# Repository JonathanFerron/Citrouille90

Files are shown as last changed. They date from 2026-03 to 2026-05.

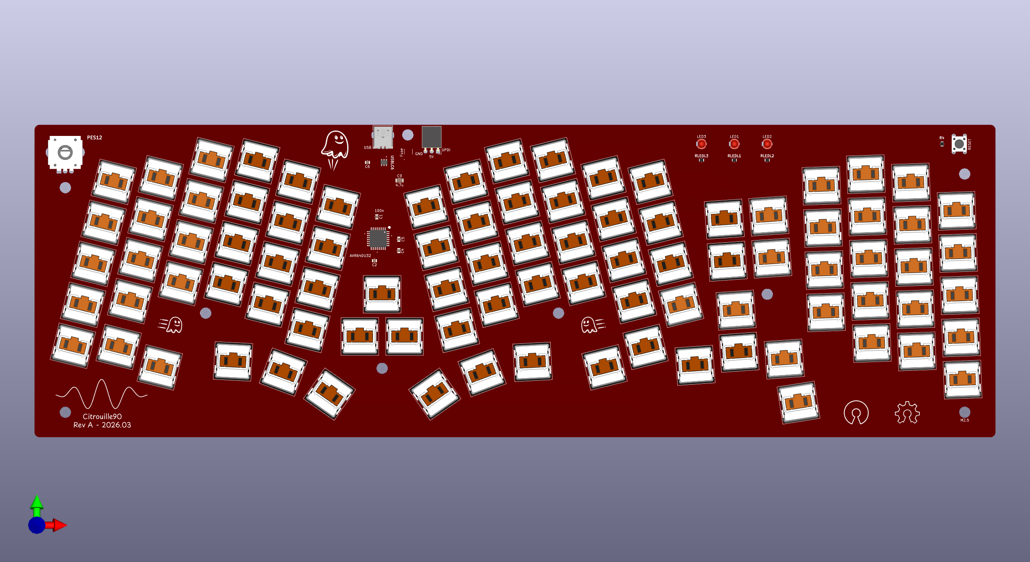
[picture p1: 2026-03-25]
doc/citrouille90 3D printout.png

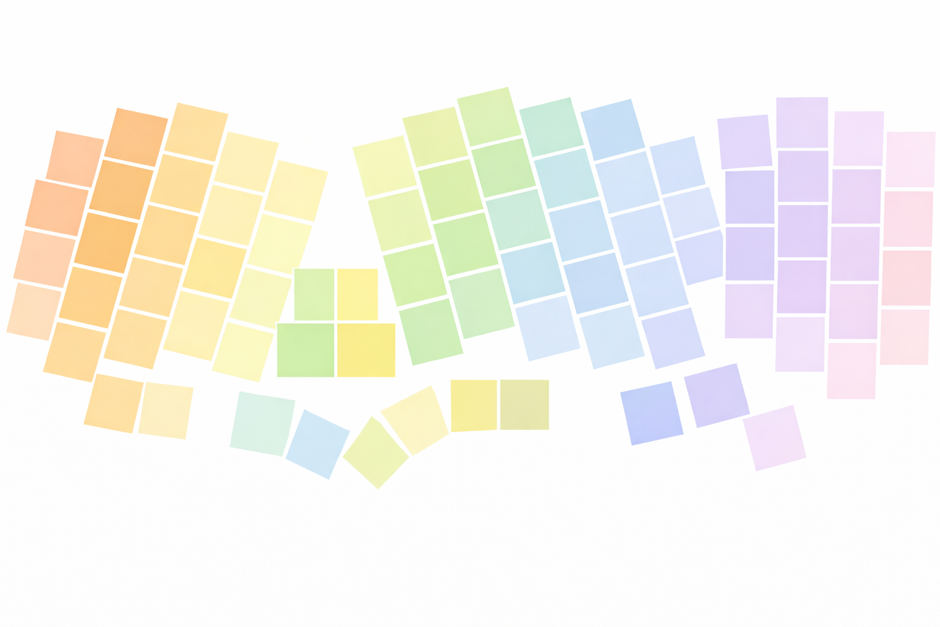
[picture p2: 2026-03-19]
doc/file_000000001a6c71f7b427a1b64068e487.png

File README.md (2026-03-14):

# Citrouille90
DIY keyboard project - AVR-DU based - Unibody, 90 keys plus encoder and leds - Covers PCB, FW (including BL) and case.

## Project Structure and Licensing

Copyright (C) 2026 Jonathan Ferron.

This project uses a multi-license stack to ensure the hardware and software remain open and reciprocal, while protecting the specific artistic assets of the design.

### 1. Hardware (PCB and Case)
The physical design files, including schematics, PCB layouts (KiCad/Gerber), and case files (STL/STEP/DXF), are licensed under the **[CERN Open Hardware Licence Version 2 – Strongly Reciprocal (CERN-OHL-S v2)](https://spdx.org/licenses/CERN-OHL-S-2.0.html)**.

*   **What this means:** You are free to make, modify, and distribute this hardware. However, if you distribute a modified version of these files or products based on them, you **must** provide the source files for your modifications under the same CERN-OHL-S v2 license.

### 2. Firmware
The source code for the keyboard firmware is licensed under the **[GNU General Public License version 3 (GPL v3)](https://www.gnu.org/licenses/gpl-3.0.txt)**.

*   **What this means:** You may run, share, and modify the software. If you distribute modified versions of the firmware, you **must** make the source code available to the recipients under the GPL v3.

### 3. Artwork
All artistic assets, including logos, icons, engravings, and custom keycap legends, are licensed under the **[Creative Commons Attribution-ShareAlike 4.0 International License (CC BY-SA 4.0)](https://creativecommons.org/licenses/by-sa/4.0/)**.

*   **What this means:** You may share and adapt the artwork, provided you give appropriate credit and distribute your contributions under the same license.

---

## Disclaimer
This project is provided "as is", without warranty of any kind, express or implied. Use of these designs and code is at your own risk.

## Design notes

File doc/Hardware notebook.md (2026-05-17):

# Citrouille90 — Hardware Notebook

**Project:** Citrouille90 (AVRDU.Enc.Choc)  
**Status as of writing:** KiCad project complete and ready to send to fab. Digikey and Mouser orders staged and ready to place.  
**Document purpose:** Personal pre-build reference and permanent record. Captures all hardware decisions with rationale, the complete BOM, and assembly notes.

---

## 1. Overview

| Parameter | Value |
|---|---|
| Name | Citrouille90 (AVRDU.Enc.Choc) |
| Keys | 90 (10 rows × 9 columns matrix) |
| Physical layout | 5 rows × 20 columns |
| Switch type | Kailh Choc V1 low-profile |
| Encoder | Bourns PES12, no integrated push switch |
| Reset | Dedicated 6mm tact switch (separate from encoder)  |
| USB | Full-Speed, USB Mini-B through-hole connector |
| MCU | AVR64DU32, TQFP-32 |
| PCB | 2-layer, 387 × 126 mm |
| Case | 3D-printed sandwich mount |
| Branding | "Citrouille90" in Playpen Sans + waveform + pumpkin logo |
| PCB board marker  | Rev A — 2026.03 |
| License (PCB/case)| CERN-OHL-S v2 (strongly reciprocal) |
| License (artwork) | CC BY-SA 4.0 |
| License (firmware)| GPL v3 |
| Copyright | © 2026 Jonathan Ferron |

---

## 2. MCU

**Part:** AVR64DU32-I/PT (TQFP-32, industrial temp range)

| Parameter | Value |
|---|---|
| Flash | 64 KB |
| SRAM | 8 KB |
| Clock | 24 MHz internal oscillator (no crystal needed) |
| GPIO (usable) | 23 |
| USB | Native Full-Speed, no external PHY |
| Programming interface | UPDI |
| VDD range | 1.8 V – 5.5 V |
| USB core supply | Internal 3.3 V regulator (VUSB) |
| Package | TQFP-32, 0.8 mm pitch |

No external crystal. No external USB PHY. VUSB (3.3 V for USB core) is generated entirely on-chip from VDD — no external 3.3 V regulator needed on the PCB. The 3.3 V domain is internal to the MCU and only powers the USB phy; all GPIO and logic runs at 5 V (VDD).

---

## 3. Power Architecture

**Configuration:** USB bus powered — Datasheet Power Configuration 5b.

```
USB Host (5 V VBUS)
    │
    ├─── Polyfuse (500 mA) ───┬─── 4.7 µF bulk cap (to GND)
    │                         │
    └─────────────────────────┴─── VDD (MCU pins 18, 28)
                                        │
                                   Internal regulator
                                        │
                                      VUSB (MCU pin 6) ── 100 nF (to GND)
```

### 3.1 Capacitor Budget

USB specification: total downstream capacitance ≤ 10 µF.

| Capacitor | Value  | Location |
|---|---|---|
| Bulk VBUS | 4.7 µF | Near USB connector, after polyfuse |
| VDD decoupling ×2  | 100 nF | At MCU VDD pins (18 and 28) |
| VUSB decoupling | 100 nF | At MCU VUSB pin (6), to GND only |
| ESD IC decoupling  | 100 nF | Near USBLC6-2 |
| Reset filter cap | 100 nF | At RESET pin (see section 8) |
| **Total** | **5.2 µF** | Well under 10 µF limit |

VUSB pin is decoupled to GND only — no external load on this pin. The internal regulator is sized for the USB PHY only.

### 3.2 Polyfuse

- **Part:** Bourns PTC reset fuse, 500 mA hold, 15 V, 1812 package
- Placed on VBUS line between USB connector and bulk capacitor
- Protects host port from overcurrent faults

---

## 4. GPIO Allocation

Total usable GPIO: **23 pins** (RESET and UPDI are dedicated, not counted).

| Function | Port / Pin  | Pin # (TQFP) | Notes |
|---|---|---|---|
| Matrix row 0 | PA0 | 30 | Pull-up input |
| Matrix row 1 | PA1 | 31 | Pull-up input |
| Matrix row 2 | PA2 | 32 | Pull-up input |
| Matrix row 3 | PA3 | 1 | Pull-up input |
| PWM LED A | PA4 | 2 | TCA0 WO4 output |
| PWM LED B | PA5 | 3 | TCA0 WO5 output |
| Matrix row 4 | PA6 | 4 | Pull-up input |
| Encoder A | PA7 | 5 | Plain input, no internal pull-up |
| Encoder B | PC3 | 9 | Plain input, no internal pull-up |
| Matrix row 5 | PD0 | 10 | Pull-up input |
| Matrix row 6 | PD1 | 11 | Pull-up input |
| Matrix row 7 | PD2 | 12 | Pull-up input |
| Matrix row 8 | PD3 | 13 | Pull-up input |
| Matrix row 9 | PD4 | 14 | Pull-up input |
| Matrix col 0 | PD5 | 15 | Output, input buffer disabled |
| Matrix col 1 | PD6 | 16 | Output, input buffer disabled |
| Matrix col 2 | PD7 | 17 | Output, input buffer disabled |
| Matrix col 3 | PF0 | 20 | Output, input buffer disabled |
| Matrix col 4 | PF1 | 21 | Output, input buffer disabled |
| Matrix col 5 | PF2 | 22 | Output, input buffer disabled |
| Matrix col 6 | PF3 | 23 | Output, input buffer disabled |
| Matrix col 7 | PF4 | 24 | Output, input buffer disabled |
| Matrix col 8 | PF5 | 25 | Output, input buffer disabled |

**Dedicated pins (not GPIO):**
- Pin 26: RESET (tact switch)
- Pin 27: UPDI (programming header)
- Pin 6: VUSB (decoupling cap only)
- Pins 18, 28: VDD
- Pins 7, 19, 29: GND

**No PORTB on AVR64DU32** — PORTB does not exist on this device.

---

## 5. USB Interface

### 5.1 Connector

- **Type:** USB Mini-B, through-hole
- **Position:** Top edge of PCB, aligned with middle of function key row

### 5.2 ESD Protection

- **Part:** USBLC6-2SC6 (SOT-23-6)
- Placed between USB connector and MCU D+/D− lines
- 100 nF decoupling cap on the IC supply pin
- No level shifting needed — PCB VDD is 5 V, MCU USB lines are 3.3 V tolerant via internal regulator

### 5.3 USB Shield RC Termination

- 1 MΩ resistor + 4.7 nF capacitor (0805, bottom layer) from USB shield to GND
- Reduces EMI from shield floating

### 5.4 Differential Pair Routing

- D+ and D− routed as matched-length differential pair
- No impedance-controlled routing required at Full-Speed (12 Mbit/s)
- Keep away from switching signals (matrix column drives, PWM)
- DRC rules: custom `.kicad_dru` with differential pair clearance and length-matching constraints

---

## 6. Key Matrix

| Parameter | Value |
|---|---|
| Electrical layout | 10 rows × 9 columns |
| Physical layout | 5 rows × 20 columns |
| Switch type | Kailh Choc V1 low-profile |
| Diode per switch | Yes — 1N4148W, SOD-123 |
| Diode orientation | COL2ROW (cathode toward column) |
| Scan direction | Drive column low, read row (pull-up) |
| Scan rate | 1000 Hz |
| Rollover | 6KRO (6-key rollover + modifiers) |

### 6.1 Diode Notes

1N4148W in SOD-123 is hand-solderable with a fine tip (T18-C2 or T18-D12) and flux. SOD-123 preferred over SOD-323 for easier hand assembly. Leaded solder (63/37, 290–315 °C).

---

## 7. Rotary Encoder

### 7.1 Part

**Bourns PES12** — mechanical rotary encoder, no integrated push switch.

| Parameter | Value |
|---|---|
| Max contact bounce | 5 ms |
| Max rotation speed | 60 RPM |
| Detents per revolution | 24 |
| Pulses per revolution | 24 |
| Detent-to-detent at 60 RPM  | ~41.7 ms |
| Quadrature transitions / detent | 4 |

### 7.2 RC Filter Circuit

Bourns-recommended RC filter on both encoder terminals A and B. This is a hardware decision that eliminates most software debounce complexity.

**Per pin:**

```
VDD (5 V) ──── 10 kΩ (pull-up) ────┬──── MCU GPIO (plain input, no internal pull-up)
                                    │
                              10 kΩ (series)
                                    │
                                Terminal (A or B)
                                    │
                              10 nF (to GND)

Terminal C ──── GND
```

**RC time constant:** 10 kΩ × 10 nF = **100 µs**

This suppresses contact bounce spikes faster than ~300–500 µs rise/fall before they reach the MCU. 100 µs is well below the 1 ms scan interval, so legitimate quadrature transitions are unaffected.

**Critical:** Configure encoder GPIO pins as plain input with **no internal pull-up**. The external 10 kΩ pull-up to VDD defines the operating point. Enabling the internal pull-up shifts the RC time constant and may degrade filtering.

### 7.3 Encoder Position

Top-left of PCB.

---

## 8. Reset Circuit

- **Switch:** 6 mm × 6 mm through-hole tact switch, SPST normally open
- **Position:** Top-right corner of PCB, silkscreen label "RESET"
- **Connection:** Switch one terminal to RESET pin (MCU pin 26), other terminal to GND

**RC filter (per AVR-DU datasheet recommendation):**

```
RESET pin (MCU pin 26) ──── 330 Ω ──── tact switch ──── GND
                │
              100 nF
                │
               GND
```

The 330 Ω series resistor limits current during ESD events. The 100 nF cap filters glitches. This is the AVR-DU datasheet recommended reset circuit.

**Behavior:** Hardware reset, always functional regardless of firmware state. Does not enter bootloader (GPR cleared on power-on reset; RESET pin behavior to be confirmed by GPR retention test on Curiosity Nano — see firmware notebook section 18.2).

---

## 9. LEDs

### 9.1 Power LED

| Parameter | Value |
|---|---|
| Type | 3 mm through-hole amber, diffused  |
| Drive | Fixed resistor from VDD — no GPIO, no PWM |
| Resistor | 2.2 kΩ |
| Target current | ~1.4 mA |
| Brightness intent | Dim but visible in low light; dim in bright room |
| Resistor placement | Near LED, not near MCU (reduces EMI, simplifies rework) |

**Calculation:** (5 V − 2.1 V forward voltage) / 2200 Ω ≈ 1.3 mA. Conservative — this LED is purely a power-on indicator.

### 9.2 Indicator LEDs (×2)

| Parameter | Value |
|---|---|
| Type | 3 mm through-hole amber, diffused  |
| Drive | MCU GPIO with PWM (TCA0) |
| Resistor each  | 390 Ω |
| Target current | ~7.5 mA at 100% duty cycle |
| Brightness | Firmware-controlled; clearly visible in bright room at full brightness |
| Viewing angle  | 60–100° preferred (soft glow, not a sharp spot) |

**Calculation:** (5 V − 2.1 V) / 390 Ω ≈ 7.4 mA. Reasonable for indicator use; well within MCU GPIO drive capability.

### 9.3 PWM Implementation

**Timer:** TCA0 in split mode — drives both LEDs independently from a single timer.

**Frequency:** 1465 Hz

1465 Hz is above the ~50–100 Hz flicker fusion threshold — no visible flicker at any duty cycle. PWM runs entirely in hardware; CPU has no per-cycle obligation (no matrix scan interference).

**Pin routing via TCAROUTEA (PORTMUX):**

TCA0 WO outputs available per PORTMUX setting:

| TCAROUTEA[2:0] | Port  | WO0  | WO1  | WO2  | WO3  | WO4  | WO5  |
|---|---|---|---|---|---|---|---|
| 0x0 | PORTA | PA0  | PA1  | PA2  | PA3  | **PA4** | **PA5** |
| 0x3 | PORTD | PD0  | PD1  | PD2  | PD3  | PD4  | PD5  |
| 0x5 | PORTF | PF0  | PF1  | PF2  | PF3  | PF4  | PF5  |

LED A → **PA4 (TCA0 WO4)**, LED B → **PA5 (TCA0 WO5)** with TCAROUTEA = 0x0 (PORTA). This avoids conflicts with matrix rows (PA0–PA3, PA6) and encoder (PA7).

### 9.4 LED Positions

Three LEDs arranged horizontally near top edge, offset to the right. Power LED leftmost, two indicator LEDs to its right.

---

## 10. UPDI Programming Header

- **Connector:** 3-pin through-hole header (2.54 mm pitch)
- **Pinout:** GND — UPDI — VCC
- **Position:** PCB top edge (preferred for easy access)
- **Programmer:** CH340-based SerialUPDI dongle (Adafruit UPDI friend)
- **Software:** avrdude with serialupdi programmer

**Critical rule: Never disable UPDI in fuses.** UPDI is the only recovery path if firmware is corrupted or the bootloader fails. Disabling it bricks the board and the only recovery path is a 12V UPDI programmer.

---

## 11. PCB Notes

| Parameter | Value |
|---|---|
| Layers | 2 |
| Dimensions | 387 × 126 mm |
| Mounting holes | M2.5, 7-hole layout |
| Silkscreen | Minimalist; logo + "Rev A — 2026.03" board marker |
| DRC rules | Custom `.kicad_dru` with USB differential pair clearance and length-matching |
| USB connector | Top edge, center of function row |
| Encoder | Top-left |
| LEDs | Top edge, right of center |
| RESET switch | Top-right corner |
| UPDI header | Top edge |

### 11.1 Routing Notes

- USB D+/D− as matched-length differential pair; keep away from matrix column drive lines and PWM pins
- Polyfuse on VBUS between connector and bulk cap
- ESD protection IC (USBLC6-2) placed close to USB connector, before the MCU
- 4.7 µF bulk capacitor placed near USB connector, after polyfuse
- 100 nF decoupling caps placed at their respective MCU pins, not clustered
- Resistor for power LED placed near LED (not near MCU)
- Encoder RC filter components placed close to encoder terminals, not at MCU side

---

## 12. Case

| Parameter | Value |
|---|---|
| Type | Sandwich mount |
| Material | 3D-printed PLA or PETG |
| Switch plate thickness | 2.2 mm (Kailh Choc V1 spec) |
| Parts | Top plate, bottom case, encoder knob |
| CAD source | Fusion 360 (`.f3d`), STEP export (`.step`) |
| STL exports | `top_plate.stl`, `bottom_case.stl`, `encoder_knob.stl` |
| Mounting | M2.5 screws through 7-hole pattern matching PCB |
| Feet | Rubber adhesive feet on bottom case |

---

## 13. Bill of Materials

### 13.1 MCU

| Qty | Description | Value / Part # | Package |
|-----|---|---|---|
| 1 | AVR64DU32 | AVR64DU32-I/PT | TQFP-32 |

### 13.2 Switches and Diodes

| Qty | Description | Value / Part # | Package |
|-----|---|---|---|
| 90  | Kailh Choc V1 switches | CPG135001D02 (or equiv.) | Through-hole, MX-spacing |
| 90  | Switching diodes | 1N4148W | SOD-123 |

### 13.3 Encoder and Reset

| Qty | Description | Value / Part # | Package |
|-----|---|---|---|
| 1 | Rotary encoder | Bourns PES12 | Through-hole |
| 1 | Encoder knob | To suit PES12 shaft | — |
| 1 | Reset tact switch | 6 mm × 6 mm SPST NO | Through-hole |

### 13.4 USB

| Qty | Description | Value / Part # | Package |
|-----|---|---|---|
| 1 | USB Mini-B connector | — | Through-hole |
| 1 | Polyfuse | Bourns PTC, 500 mA, 15 V | 1812 |
| 1 | ESD protection IC | USBLC6-2SC6 | SOT-23-6  |

### 13.5 Capacitors

| Qty | Description | Value | Voltage | Package | Notes |
|-----|---|---|---|---|---|
| 1 | Bulk VBUS capacitor | 4.7 µF | 16 V | 1206 | X7R or X5R ceramic, near USB connector |
| 5 | Decoupling capacitors | 100 nF | — | 0805 | 2× VDD (MCU), 1× VUSB (MCU), 1× ESD IC, 1× RESET filter |

### 13.6 Capacitors (Encoder Filter and USB Shield)

| Qty | Description | Value | Package | Notes |
|-----|---|---|---|---|
| 2 | Encoder RC filter caps | 10 nF | 0805 | One per encoder pin (A, B), pin to GND  |
| 1 | USB shield RC cap | 4.7 nF  | 0805 | USB shield to GND, with 1 MΩ |

### 13.7 Resistors

| Qty | Description | Value | Package | Notes |
|-----|---|---|---|---|
| 1 | Power LED current limit | 2.2 kΩ  | 0805 | ~1.4 mA at 5 V |
| 2 | PWM LED current limit | 390 Ω | 0805 | ~7.4 mA at 5 V, one per indicator LED |
| 1 | RESET series resistor | 330 Ω | 0805 | ESD protection on RESET pin |
| 2 | Encoder pull-up (per pin) | 10 kΩ | 0805 | To VDD, part of RC filter |
| 4 | Encoder series (per pin) | 10 kΩ | 0805 | Between terminal and MCU GPIO (2 per encoder pin pair — but 1 pull-up + 1 series per pin = 2 pins × 2 = 4 total) |
| 1 | USB shield termination | 1 MΩ | 0805 | USB shield to GND (with 4.7 nF cap) |

> **Encoder RC resistor count clarification:** 2 pins (A and B) × 2 resistors each (1 pull-up to VDD + 1 series to MCU GPIO) = **4 resistors of 10 kΩ** total for the encoder filter.

### 13.8 LEDs

| Qty | Description | Value / Part # | Package |
|-----|---|---|---|
| 1 | Power LED | 3 mm amber diffused | Through-hole  |
| 2 | Indicator LEDs | 3 mm amber diffused | Through-hole  |

Diffused preferred over clear — softer glow, 60–100° viewing angle, less eye-fatiguing at close range.

### 13.9 Programming Header

| Qty | Description | Value / Part # | Package |
|-----|---|---|---|
| 1 | UPDI header | 3-pin 2.54 mm male header | Through-hole  |

### 13.10 Hardware

| Qty | Description | Notes |
|-----|---|---|
| 7 | M2.5 screws | Length to suit plate + PCB + case stack |
| 7 | M2.5 nuts or standoffs | Matching |
| 4+  | Rubber adhesive feet | Applied to bottom of case |
| 90  | Kailh Choc-compatible keycaps | MBK, CFX, or similar Choc-spacing profile |

---

## 14. Assembly Notes

### 14.1 Soldering Notes

- Leaded solder preferred: 63/37, 290–315 °C
- SMD diodes (SOD-123): T18-C2 or T18-D12 tip, flux generously
- TQFP-32 MCU: drag solder with flux, wick bridges immediately
- ESD IC (SOT-23-6): small pads, flux and fine tip
- Through-hole components (switches, encoder, LEDs, reset switch, UPDI header): standard iron, 350 °C

### 14.2 Assembly Order (recommended)

1. SMD passives first (resistors, capacitors) — before through-hole, easier to access pads
2. ESD IC (USBLC6-2) and polyfuse
3. MCU (TQFP-32) — inspect under magnification, check for bridges before powering
4. USB connector
5. Reset tact switch and UPDI header
6. LEDs (check orientation — anode/cathode markings)
7. Encoder
8. Diodes (90×) — check cathode band direction (COL2ROW: cathode toward column pin)
9. Kailh Choc switches last (after all SMD and smaller TH components)

### 14.3 First Power-On Checklist

Before loading any firmware:
- [ ] Verify 5 V at VDD test point (no short to GND)
- [ ] Verify power LED illuminates
- [ ] Connect UPDI programmer, confirm avrdude detects AVR64DU32
- [ ] Read device signature to confirm correct MCU
- [ ] Flash test firmware (blink LED, confirm PWM pins respond)
- [ ] Test matrix continuity (short each switch, check scan output)
- [ ] Test encoder (confirm A/B pulses reach MCU pins)
- [ ] Test reset button (confirm system resets cleanly)

### 14.4 UPDI Recovery

If firmware is corrupted and USB is non-functional, UPDI is the only recovery path. Always keep the SerialUPDI programmer accessible.

---

## 15. Open Hardware Items

| Item | Status | Notes |
|---|---|---|
| Encoder knob selection | 🔧 Pending | Choose to suit PES12 shaft spec |
| 3D case design | 🔧 Pending | Switch plate 2.2 mm; Fusion 360 source to be created |

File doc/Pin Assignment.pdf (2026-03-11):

# AVR64DU32 — 32-Pin Package

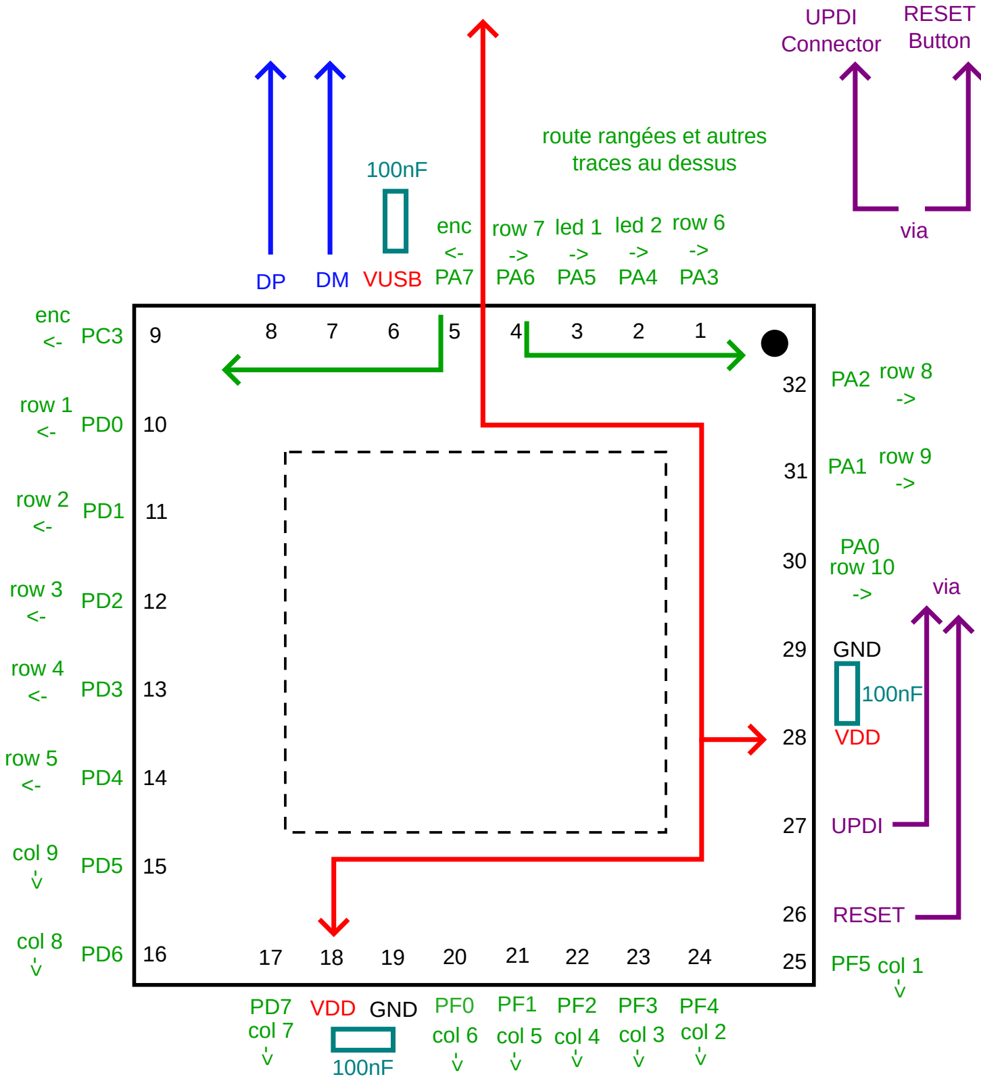
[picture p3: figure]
GND; VDD; UPDI; RESET; DM VUSB PA7; PD7 VDD GND PF0 PF1 PF2 PF3 PF4; row 7 ->; enc <-; led 1 ->; led 2 ->; row 6 ->; row 8 ->; row 9 ->; row 10 ->; row 1 <-; row 2 <-; row 3 <-; row 4 <-; row 5 <-; col 9; col 8 ->; col 7 ->; col 6 ->; col 5 ->; col 4 ->; col 3 ->; col 2 ->; col 1 ->; via; UPDI Connector; RESET Button; route rangées et autres traces au dessus

via pour chaque colonne
(route colonnes en dessous)

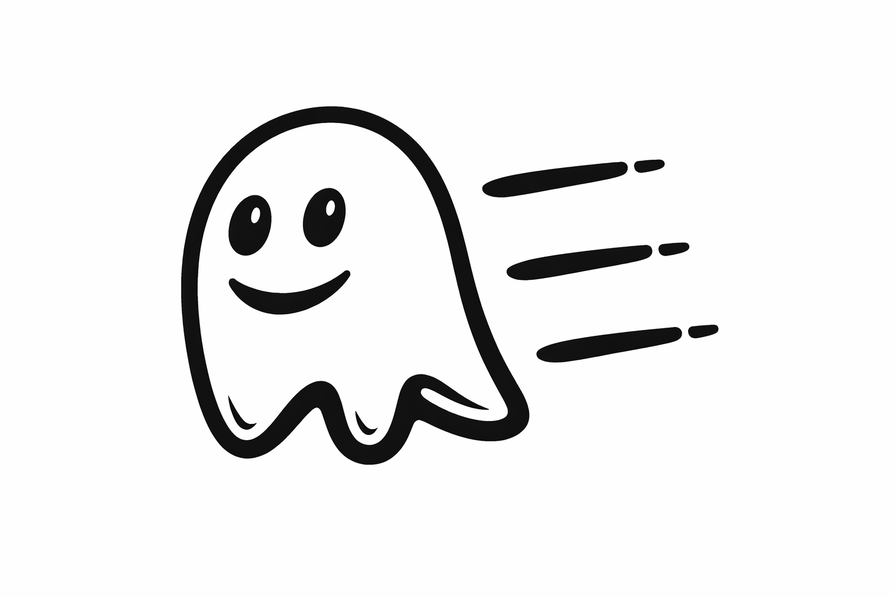
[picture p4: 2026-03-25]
doc/file_00000000e3d071fd9366121f5f05d2d4.png

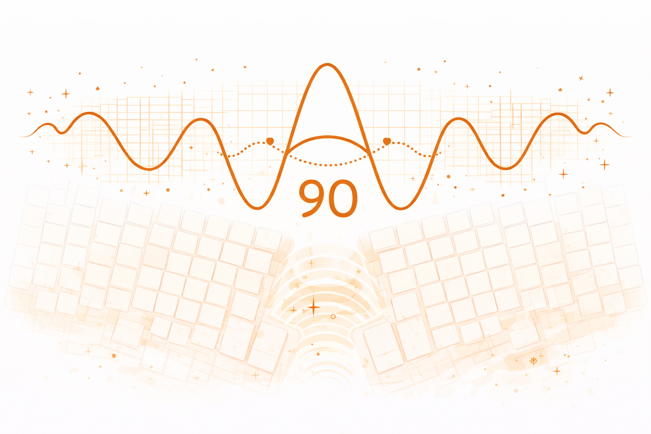
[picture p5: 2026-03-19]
doc/file_00000000508071f58be6d0860e3f69f2.png

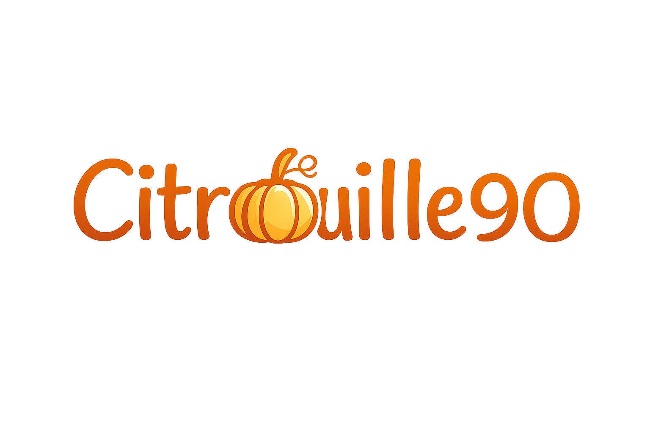
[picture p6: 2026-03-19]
doc/file_000000007074720cb7dd78ddb676f850.png

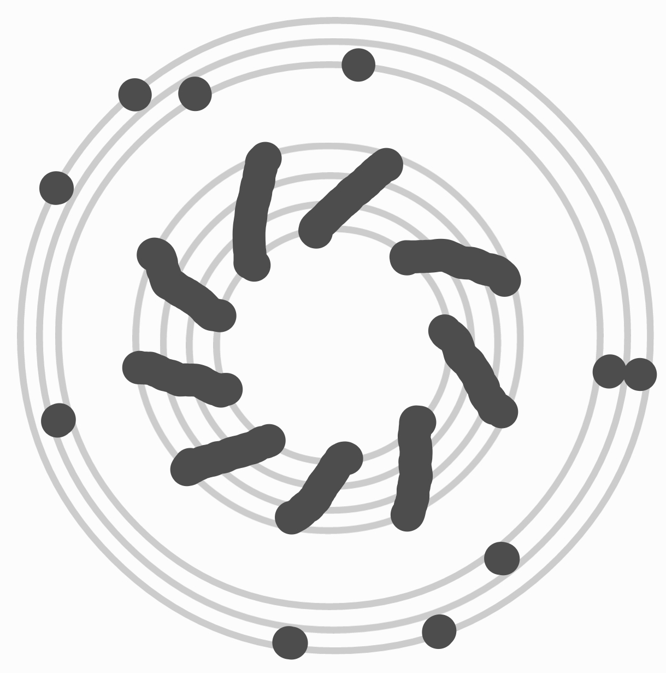
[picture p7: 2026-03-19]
doc/Screenshot_20260309_205730_Samsung Notes.jpg

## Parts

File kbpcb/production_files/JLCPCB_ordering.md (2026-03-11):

# JLCPCB ordering guidelines

The information below is aimed at helping users not familiar to PCB design and/or manufacturing to easily order Type S or Type H PCBs at JLCPCB.

JLCPCB already provides generic infornmation on how to order PCBs and assemble them, you'll find this information on the links below:
* https://jlcpcb.com/help/article/54-How-do-I-place-an-order
* https://jlcpcb.com/help/article/342-how-do-i-place-a-pcba-order

As for ordering FR4 plates, either full or half, the process is even simpler as there is no assembly process.  
In this case follow the same steps up to ***Advanced Options***.  
For the ***PCB Specifications*** section you can leave all options by default and just select the PCB color you want.

## Connecting to JLCPCB website

Go to https://jlcpcb.com website.



Click on *'Sign in'*, if you do not have an account it is time to create one by selecting *'New Customer? Start Here'*.

Once you are logged, you should see your user account displayed on the top right.

## Starting a new order

To start click on the *'Instant Quote'* button

You'll then have the following information displayed.



## Upload gerber file

Click on *'Add gerger file'* and select one of those files:
* **production_files/typeH/jlcpcb/GERBER-Phoenix_Project_No1-TypeH.zip** for the Type H PCB
* **production_files/typeS/jlcpcb/GERBER-Phoenix_Project_No1-TypeS.zip** for the Type S PCB

Wait a bit while the file is processed, to have the following information displayed:



PCB dimensions are automatically calculated and a price is already given with all defauts options.
In this section we will leave all the default parameters as is, with the exception of *'PCB Qty'* if you want to order more than 5 PCBs.

## Tweaking PCB Specifications

By default you will have the following parameters:



It is perfectly fine to keep them as is to have a working PCB, but will do a few tweaks.



I strongly recommend selecting *'LeadFree HASL'*:
* Go lead free, it is more environmentally friendly.
* It adds only 1.80$ to the cost of 5 PCB compared to default *'HASL(with lead)'*.
* *'ENIG'* adds 18.70$, a significant expense not justified in this case as no gold will be visible after soldering.

I selected *'Black'* for the PCB color(I love the satin finish of their black soldermask) but you can pick any color you want.  
If you select *'White'* the silkscreen color will then be black. 

## Tweaking High-spec Options

By default you will have the following parameters:



I removed the order number to have this:



Keep in mind that it adds 1.52$ to remove the order number.  
You can perfectly keep the option *'Remove Order Number'* to *'No'*, JLCPCB will automatically place this number on the PCB were it is the most appropriate, and will most probably place it on the cutout tabs that will later be snapped off(but no warranty on that).

## Advanced Options

No need to touch that.

## Tweaking PCB Assenbly

In this section:



Click the slide button on the right to open the following page:



We will change a few options here:



### PCBA Type

It must be set to *'Standard'* in order for:
* The WS2812 mini leds to be soldered.
* The Kailh hotswap sockets to be soldered.

### Assembly Side

We select *'Bottom Side'* as it is were all our components are placed.

### PCBA Qty

If you want to save some money you can select down to 2, but keep in mind that you will still have 5 PCBs manufactured if you ordered 5 for example, 3 of them will be shipped unpopulated.
The price difference may not be significent enough to have only 2 assembled PCBs though...

### Edge Rails/Fiducials

We select *'Added by customer'* as everything is prepared on the PCB design.

### Confirm Parts Placements

I'd suggest selecting *'Yes'*.  

I previously selected *'No'* as JLCPCB usually manage this part correctly and if they have any doubts they will contact you for confirmation.  
I have been contacted previously for the WS2812 mini leds and had to explain what to do for the placement and later confirm that their placement screenshot was correct.    

If you select *'Yes'* this will force you to manually confirm components placement before the PCBs are assembled.
They will probably come back to you anyway for the leds placement and maybe also for the Kailh hotswap sockets.
This is a bit cumbersome for non PCB designers but definitely doable and will allow you to check that no mistakes have been made.
I'll give more details on parts placement confirmation later on in this document. 

### Confirm parameters

Click on *'Confirm'* button when it is done, the following page appears:



### BOM and CPL files

Click on *'NEXT'*, the folowing page appears:



Click *'Add BOM File'* and select one of those files:
* **production_files/typeH/jlcpcb/BOM-Phoenix_Project_No1-TypeH.csv** for the Type H PCB
* **production_files/typeS/jlcpcb/BOM-Phoenix_Project_No1-TypeS.csv** for the Type S PCB

Click *'Add CPL File'* and select one of those files:
* **production_files/typeH/jlcpcb/CPL-Phoenix_Project_No1-TypeH.csv** for the Type H PCB
* **production_files/typeS/jlcpcb/CPL-Phoenix_Project_No1-TypeS.csv** for the Type S PCB

You should have the follwing page displayed:



Click on *'Process BOM & CPL'*

## Bill of Material page



This page shows something interesting as there is currently an inventory shortage for one component.
This can happen often as JLCPCB tend to wait that inventories are empty before ordering new components.  

You have two solutions.

1. Play the waiting game until all components are available to make an order.
2. Find a replacement for those components.

Solution 1 is the easiest and less risky one.

But solution 2 is not as compilcated as you may think, particularly for simple passive components like capacitors, resistors, diodes and fuses.  
In this case this the reference of a resettable fuse in an imperial 805 footprint, we could hope to easily find an equivalent in stock replacement.    
If you click on the search icon of this component, immediately on the left of the *'Qty'* column, the website will propose you several alternatives that should be compatible, like below.



The list shows possible choices, all 805 footprint, from the closest match possible to the least. The first choice is the reference we had already selected but out of stock, the next two ones are also out of stock, but the fourth one is in stock and a pretty good match so this is the one I selected for my order.



After clicking *'NEXT'* the website will compute a PCB assembly preview for you.  
Depending on the server load this can take some time, don't hesitate to refresh the page (F5) if it take too long.  
You should be greated with the following visual (I pressed the *'Bottom'* button at the top to show the bottom assembly).



Don't put much of an importance on the components placement and orientation, this display has not real value and it is advertised as is.  
Components can be wrongly oriented and even in the wrong position (can even be outside the PCB area) although I have to admit that JLCPCB have made significant progress since they proposed their PCBA service.  
People at JLCPCB will inspect the data and correct everything wrong and in case of doubt they will contact you for clarification (or if you asked for a placement review before going to assembly).  

You can click *'NEXT'* as soon as this page is displayed, this will go to the quote and order page.

## Quote & Order



You aleady have a price here, not including shipping costs and taxes, here it is 112$ for 5 fully assembled PCBs so around 23$ per PCB.  
For assembled PCBs you have to declare it's purpose in the *'Product Description'* drop down menu.  



I selected DIY for the description here.



Just click *'SAVE TO CART'* and you are mostly done, except for shipping selection and payment.



## About WS2812 mini polarity and placement

This is specific polarity information to correctly place WS2812 mini leds onto the PCB.
Those leds are designed in the BOM as D1 to D16.

Please be aware that the triangle cutout of the WS2812 mini led is not indicating pin 1, but pin 3 of the chip.
The WS2812 mini footprint indicates pin 1 on the silkscreen with a dot, diametrically opposite of pin 3 indicated by the triangle cutout.

See image below for a visual explanation:



In case you asked for manually inspecting the component placement before fabrication this is a good reference for you to inspect that this component is correcty placed.  
If JLCPCB ask you how to place this component you can just copy paste the previous text section with the image for explanation.

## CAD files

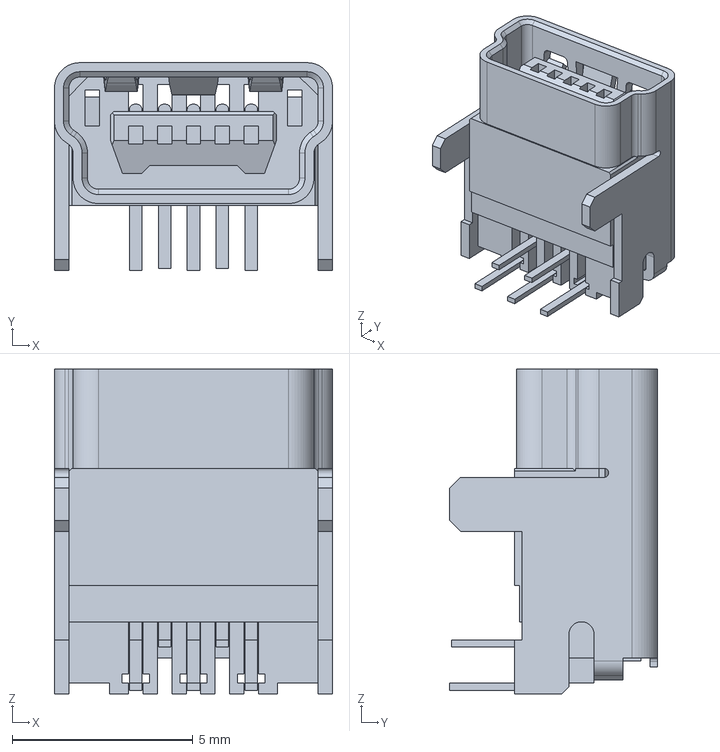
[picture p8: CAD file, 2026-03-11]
kbpcb/lib_3Dmodels/usb mini b connector.stp
7.70 x 5.75 x 9.00 mm

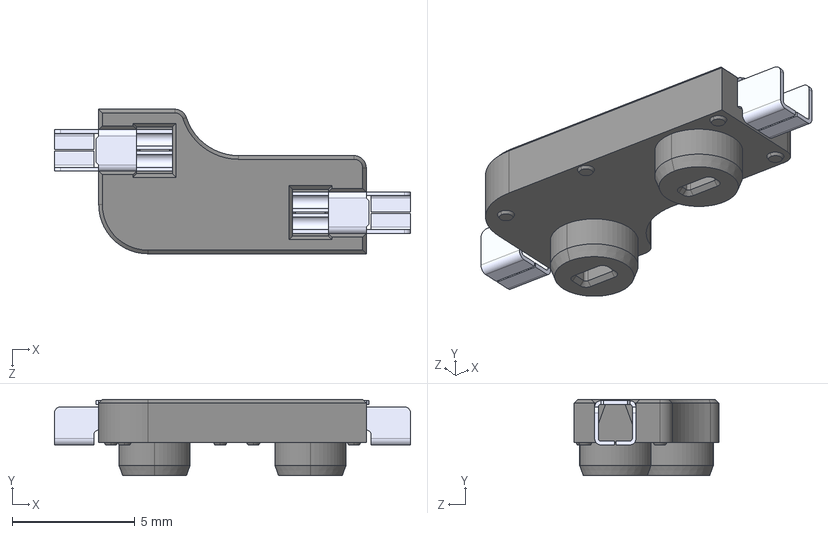
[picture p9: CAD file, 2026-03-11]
kbpcbold1/lib_3Dmodels/Kailh_PG151101S11.step
14.5 x 3.10 x 5.89 mm

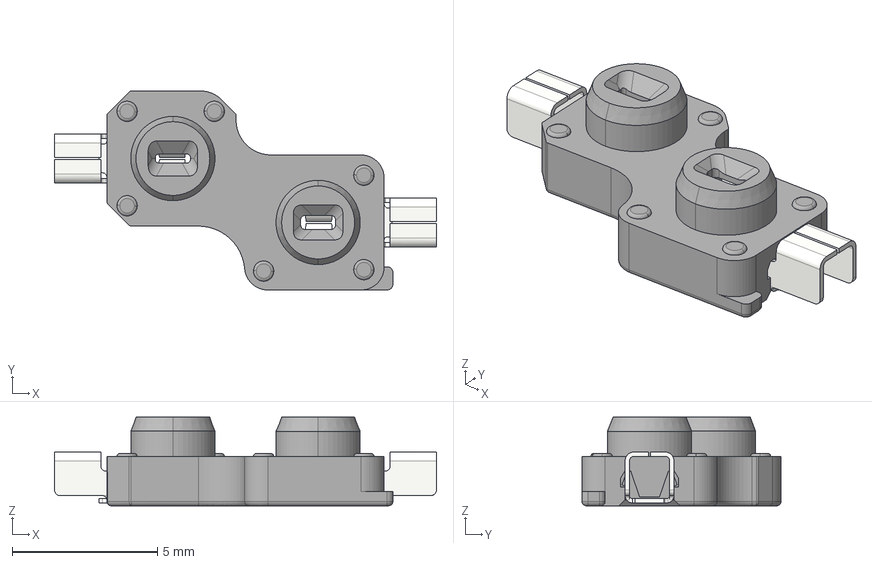
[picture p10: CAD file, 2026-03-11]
kbpcbold2/lib_3Dmodels/SW_Hotswap_Kailh_Choc_V1.stp
13.2 x 6.85 x 3.05 mm

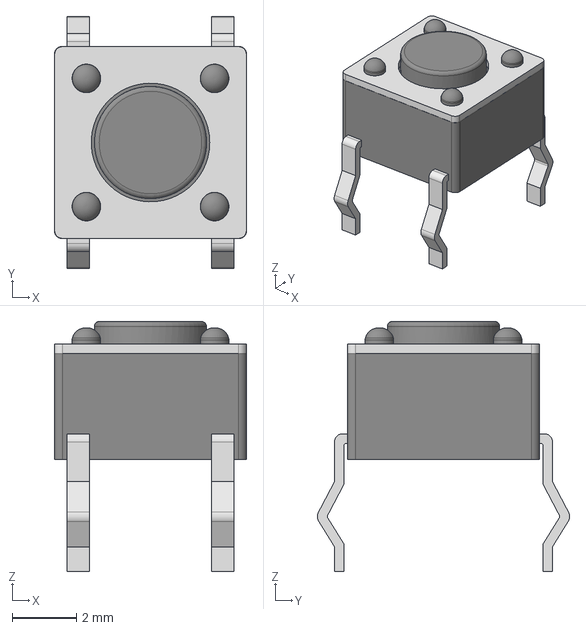
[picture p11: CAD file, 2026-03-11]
kbpcb/lib_3Dmodels/MJTP1230.stp
6.00 x 7.87 x 7.80 mm

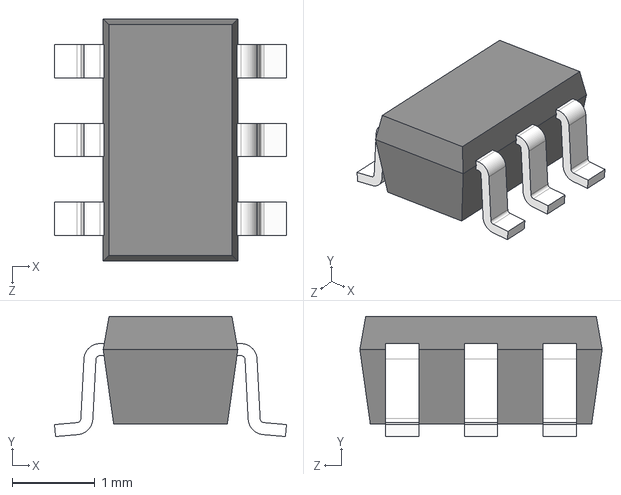
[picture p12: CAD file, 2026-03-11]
kbpcbold1/lib_3Dmodels/USBLC6-2SC6.step
2.80 x 1.45 x 2.92 mm

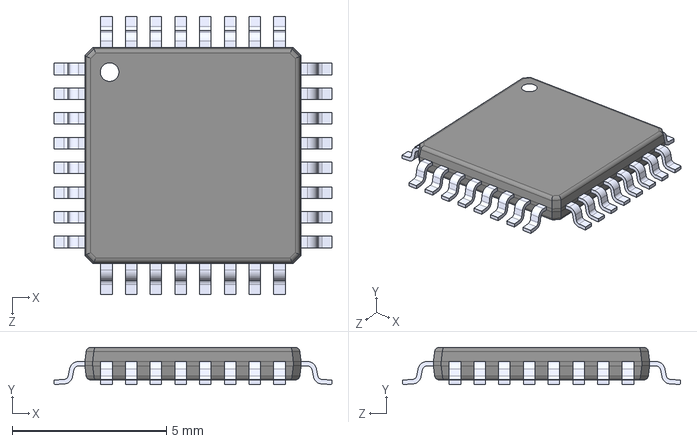
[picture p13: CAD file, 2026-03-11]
kbpcb/lib_3Dmodels/TQFP32 7x7.STEP
9.00 x 1.20 x 9.00 mm

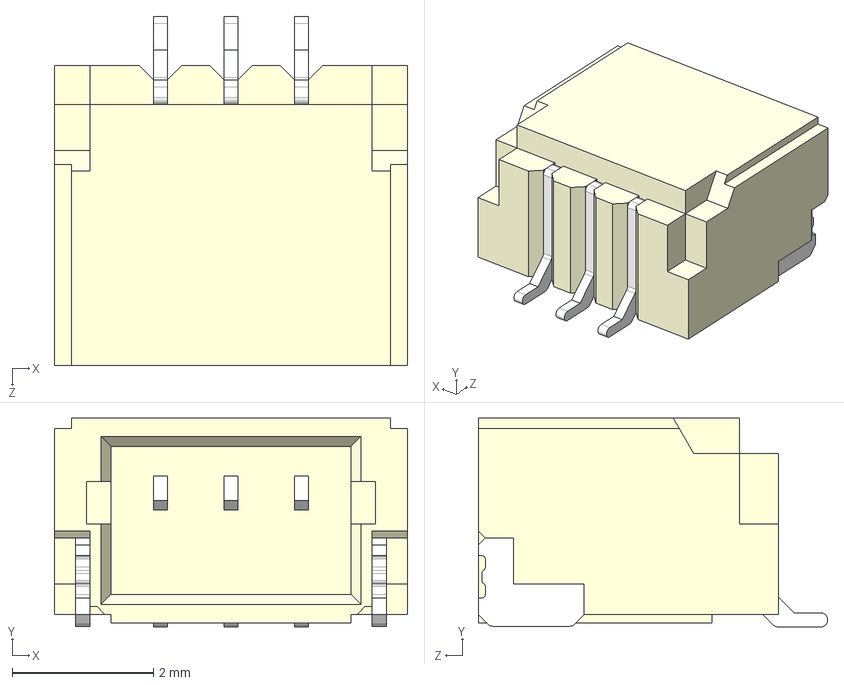
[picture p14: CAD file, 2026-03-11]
kbpcbold1/lib_3Dmodels/SM03B-SRSS-TB_LF__SN_.step
5.00 x 2.96 x 4.95 mm

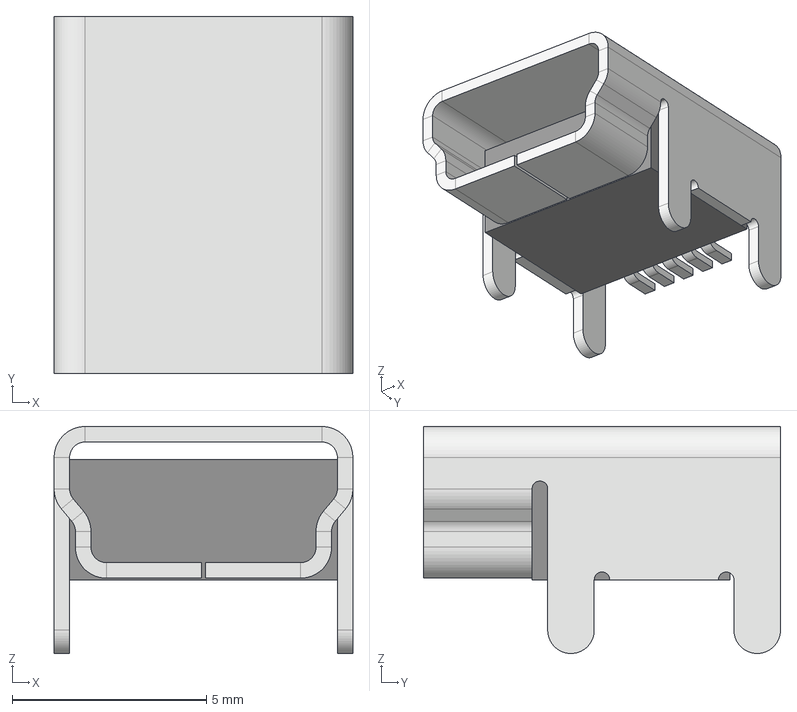
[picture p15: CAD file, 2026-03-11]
kbpcbold2/lib_3Dmodels/HRO-U-M-M5DD-W-1.step
7.70 x 9.20 x 5.85 mm
Pins
Plastic_Case

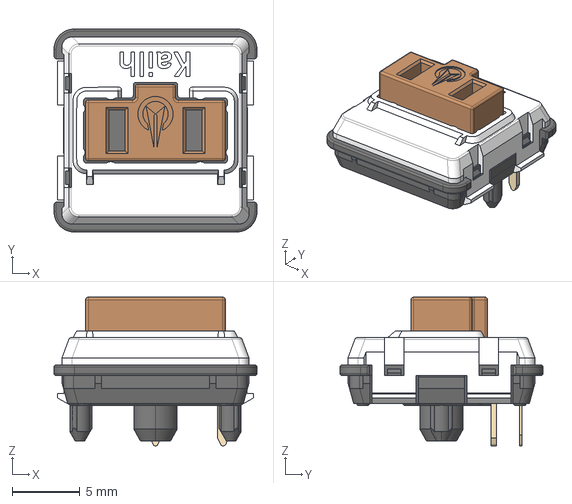
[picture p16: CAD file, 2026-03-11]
kbpcb/lib_3Dmodels/SW_Kailh_Choc_V1.stp
15.0 x 15.0 x 11.0 mm

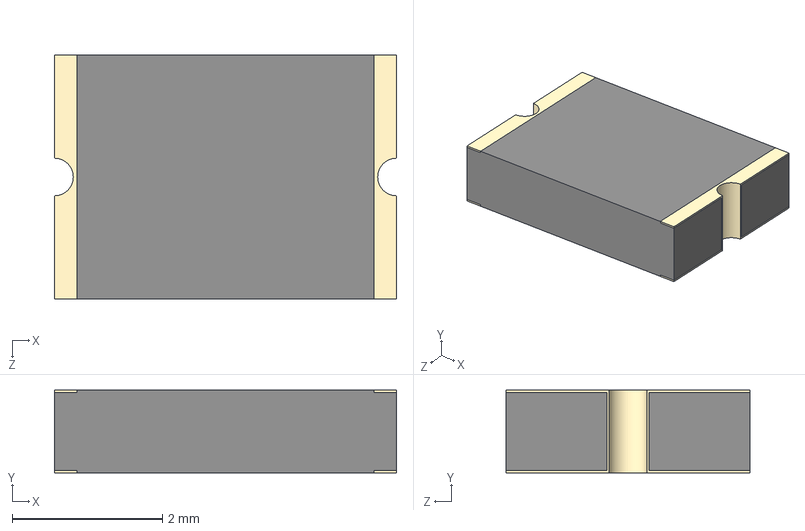
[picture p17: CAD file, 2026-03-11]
kbpcbold1/lib_3Dmodels/MF-MSMF050-2.STEP
4.55 x 1.10 x 3.24 mm

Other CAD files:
kbpcb/lib_3Dmodels/PES12-40S-N0024.stp
kbpcb/lib_3Dmodels/SM03B-SRSS-TB_LF__SN_.stp
kbpcbold1/lib_3Dmodels/PES12-40S-N0024.stp
kbpcbold1/lib_3Dmodels/SM03B-SRSS-TB_LF__SN_.stp
kbpcbold2/lib_3Dmodels/PES12-40S-N0024.stp
kbpcbold2/lib_3Dmodels/SM03B-SRSS-TB_LF__SN_.stp

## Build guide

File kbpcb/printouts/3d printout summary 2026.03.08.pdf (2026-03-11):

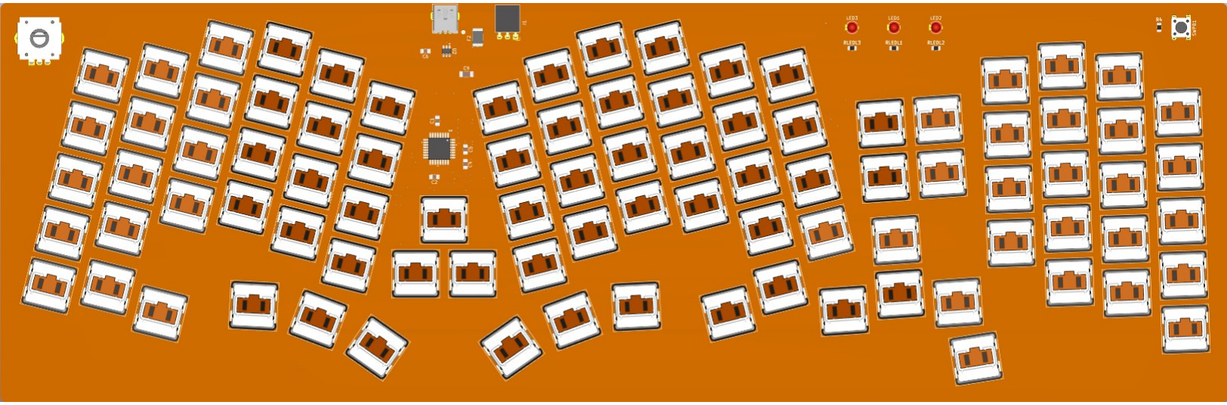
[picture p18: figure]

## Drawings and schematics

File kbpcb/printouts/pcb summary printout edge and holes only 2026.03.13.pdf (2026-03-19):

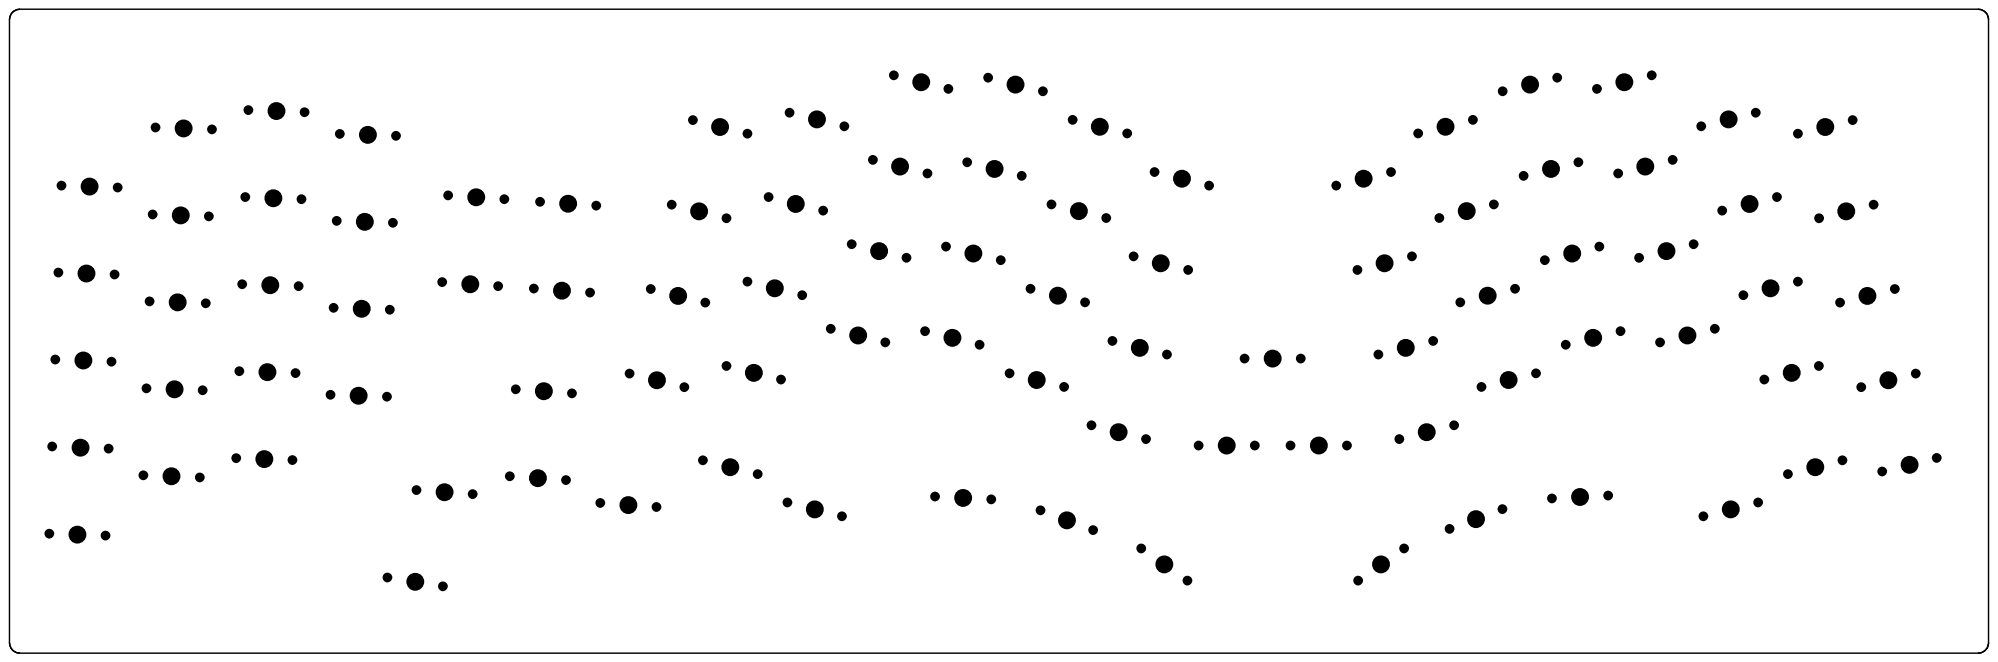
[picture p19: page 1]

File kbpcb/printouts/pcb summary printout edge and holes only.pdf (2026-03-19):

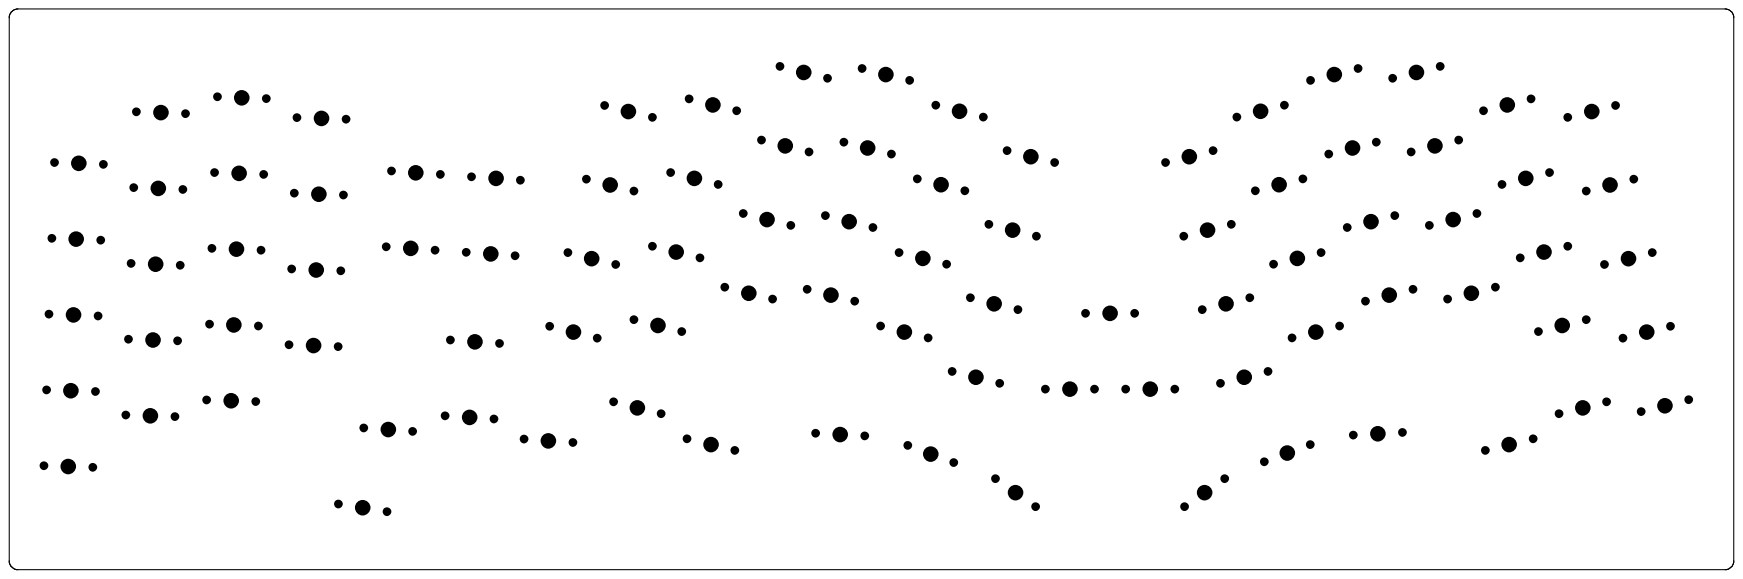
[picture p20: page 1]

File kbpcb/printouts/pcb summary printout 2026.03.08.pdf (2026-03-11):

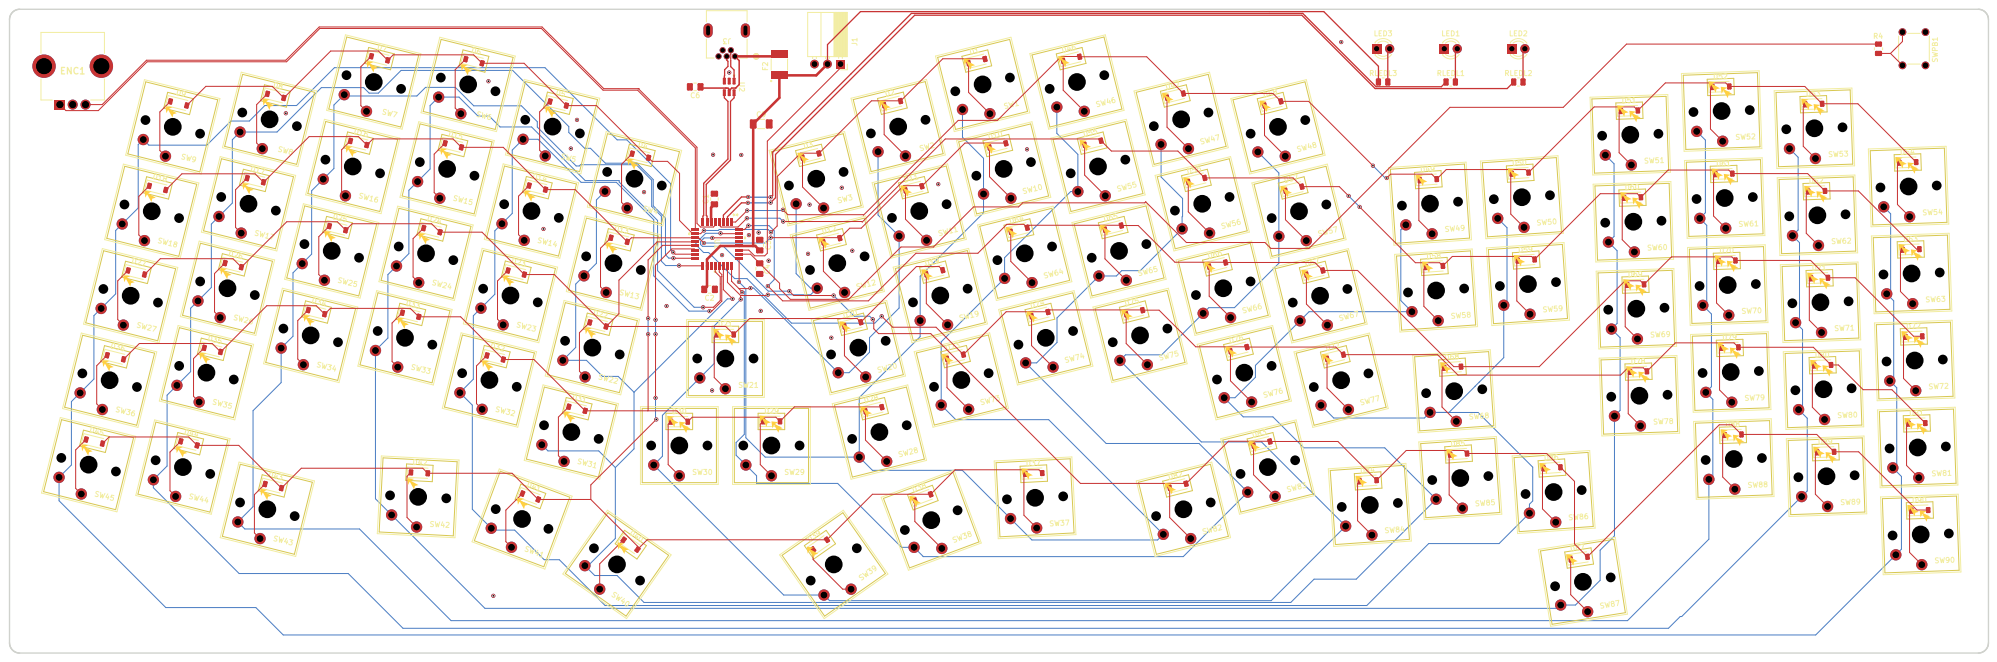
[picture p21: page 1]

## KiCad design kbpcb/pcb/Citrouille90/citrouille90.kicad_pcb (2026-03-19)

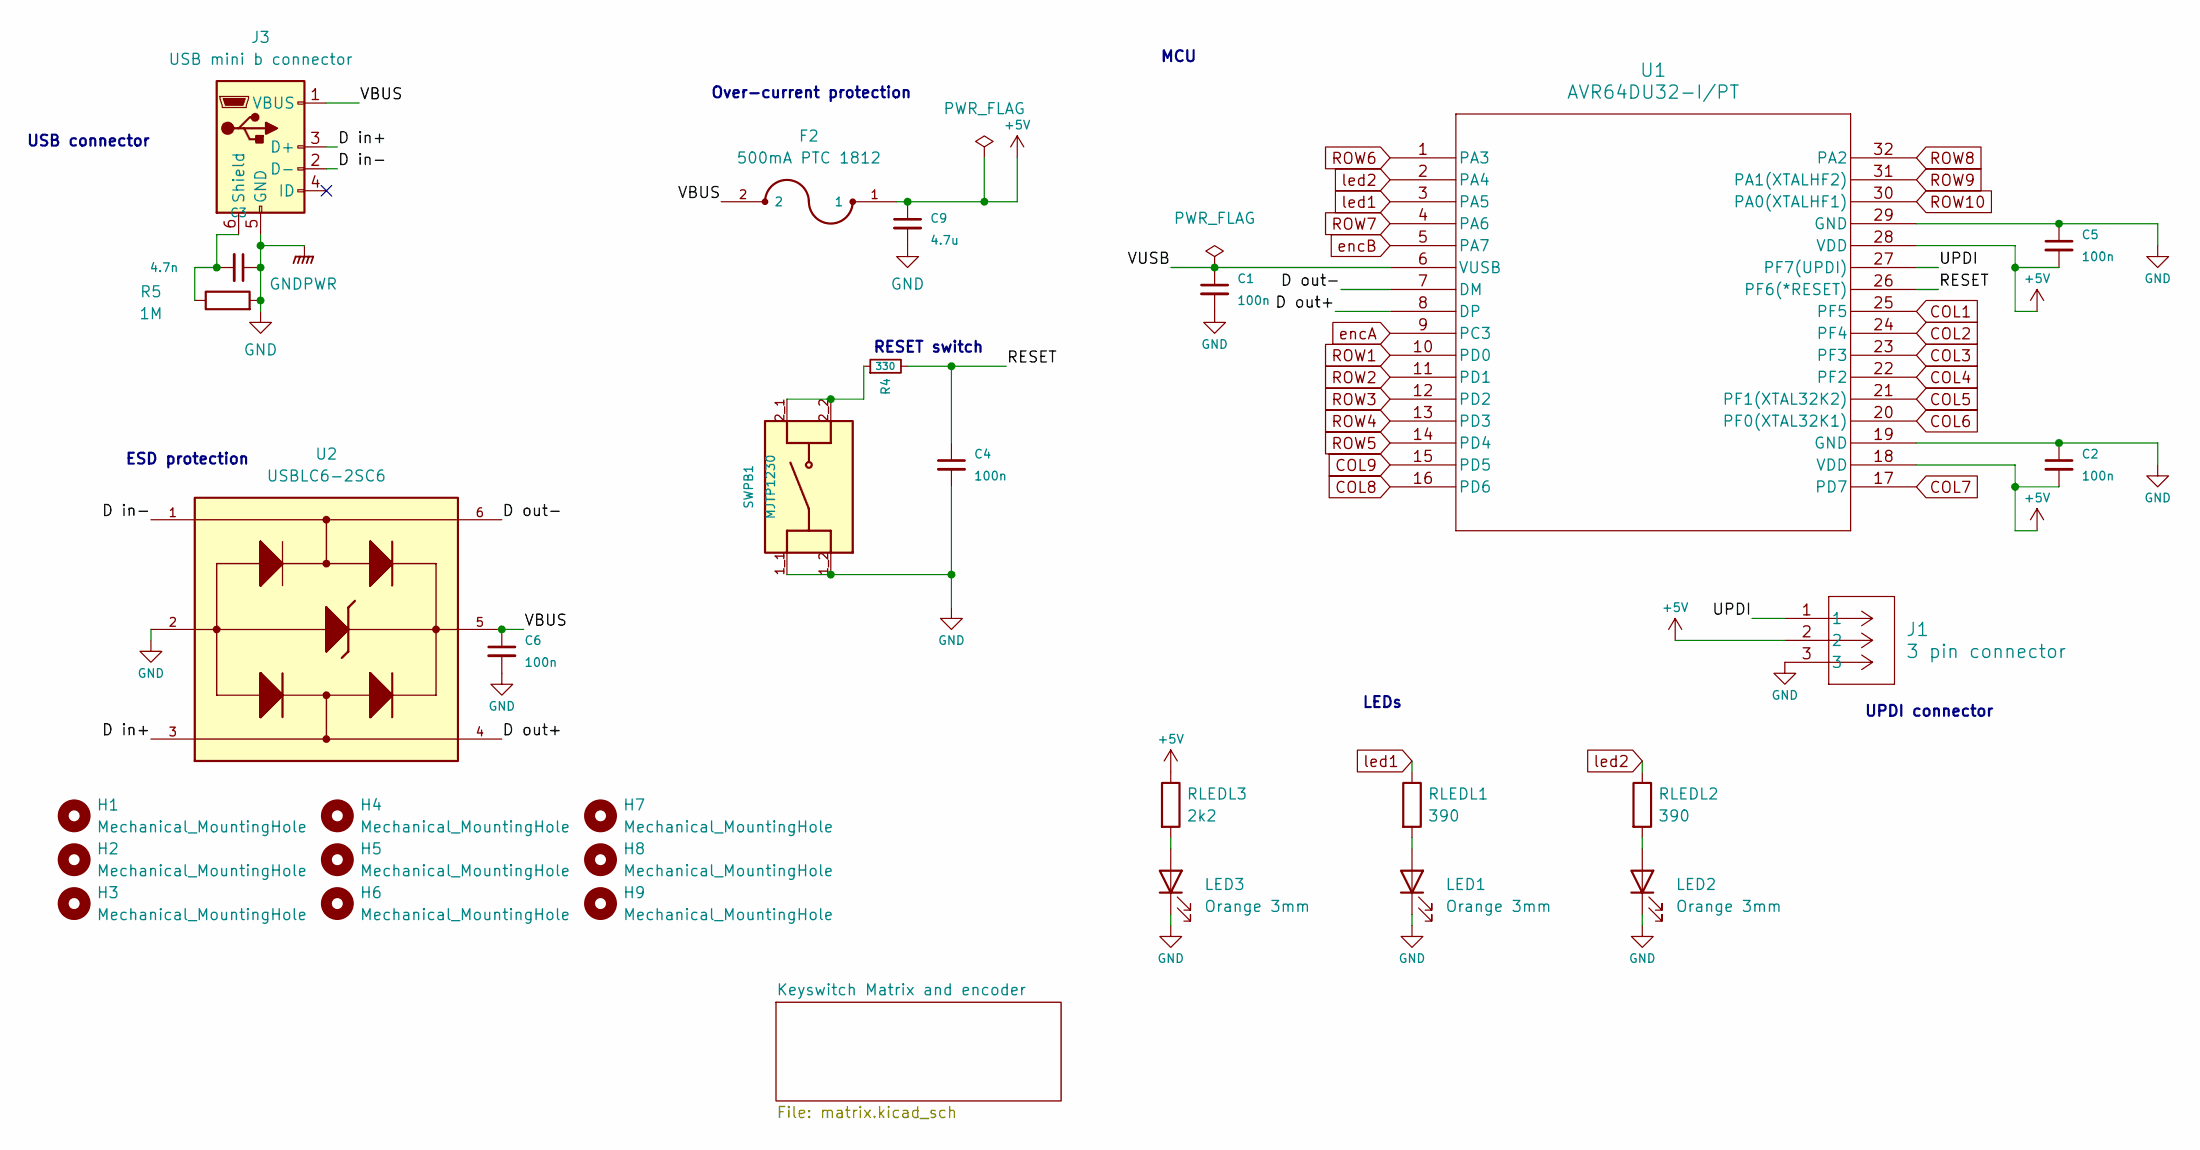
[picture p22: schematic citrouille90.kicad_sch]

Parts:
C1, C2, C4, C5: 100n; C_0805_2012Metric_Pad1.18x1.45mm_HandSolder; LCSC C1525
C3: 4.7n; C_0805_2012Metric_Pad1.18x1.45mm_HandSolder
C6: 100n; C_0805_2012Metric_Pad1.18x1.45mm_HandSolder
C9: 4.7u; C_1206_3216Metric_Pad1.33x1.80mm_HandSolder
F2: 500mA PTC 1812; FUSM4632X85
H1, H2, H3, H4, H5, H6, H7, H8, H9: Mechanical_MountingHole; MountingHole_2.7mm_M2.5_ISO7380_Pad
J1: 3 pin connector; PinSocket_1x03_P2.54mm_Horizontal
J3: USB mini b connector; usb mini connector
LED1, LED2, LED3: Orange 3mm; LED_D3.0mm
R4: 330; R_805
R5: 1M; R_805
RLEDL1, RLEDL2: 390; R_805
RLEDL3: 2k2; R_805
SWPB1: MJTP1230; SW_MJTP1230; PARTREV NA; LCSC C92584
U1: AVR64DU32-I/PT; TQFP32_PT_MCH-M
U2: USBLC6-2SC6; SOT-23-6

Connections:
+5V: C2.2, C5.2, C9.1, F2.1, J1.2, RLEDL3.1, U1.18 (VDD), U1.28 (VDD); also elsewhere on the board
/D out+: U1.8 (DP), U2.4; also elsewhere on the board
/D out-: U1.7 (DM), U2.6; also elsewhere on the board
/RESET: C4.1, R4.2, U1.26 (PF6(*RESET))
/UPDI: J1.1, U1.27 (PF7(UPDI))
/VBUS: C6.1, F2.2, J3.1 (VBUS), U2.5; also elsewhere on the board
/VUSB: C1.1, U1.6 (VUSB)
COL1: U1.25 (PF5); also elsewhere on the board
COL2: U1.24 (PF4); also elsewhere on the board
COL3: U1.23 (PF3); also elsewhere on the board
COL4: U1.22 (PF2); also elsewhere on the board
COL5: U1.21 (PF1(XTAL32K2)); also elsewhere on the board
COL6: U1.20 (PF0(XTAL32K1)); also elsewhere on the board
COL7: U1.17 (PD7); also elsewhere on the board
COL8: U1.16 (PD6); also elsewhere on the board
COL9: U1.15 (PD5); also elsewhere on the board
GND: C1.2, C2.1, C3.1, C4.2, C5.1, C6.2, C9.2, J1.3, J3.5 (GND), LED1.1 (K), LED2.1 (K), LED3.1 (K), R5.2, SWPB1.1_1, SWPB1.1_2, U1.19 (GND), U1.29 (GND), U2.2; also elsewhere on the board
unnamed: J3.2 (D-), U2.1
unnamed: J3.3 (D+), U2.3
unnamed 112: C3.2, J3.6 (Shield), R5.1; also elsewhere on the board
unnamed: LED1.2 (A), RLEDL1.2
unnamed: LED2.2 (A), RLEDL2.2
unnamed: LED3.2 (A), RLEDL3.2
unnamed 116: R4.1, SWPB1.2_1, SWPB1.2_2; also elsewhere on the board
ROW1: U1.10 (PD0); also elsewhere on the board
ROW2: U1.11 (PD1); also elsewhere on the board
ROW3: U1.12 (PD2); also elsewhere on the board
ROW4: U1.13 (PD3); also elsewhere on the board
ROW5: U1.14 (PD4); also elsewhere on the board
ROW6: U1.1 (PA3); also elsewhere on the board
ROW7: U1.4 (PA6); also elsewhere on the board
ROW8: U1.32 (PA2); also elsewhere on the board
ROW9: U1.31 (PA1(XTALHF2)); also elsewhere on the board
ROW10: U1.30 (PA0(XTALHF1)); also elsewhere on the board
encA: U1.9 (PC3); also elsewhere on the board
encB: U1.5 (PA7); also elsewhere on the board
led1: RLEDL1.1, U1.3 (PA5)
led2: RLEDL2.1, U1.2 (PA4)

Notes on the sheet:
Over-current protection
ESD protection
MCU
RESET switch
LEDs
UPDI connector
USB connector

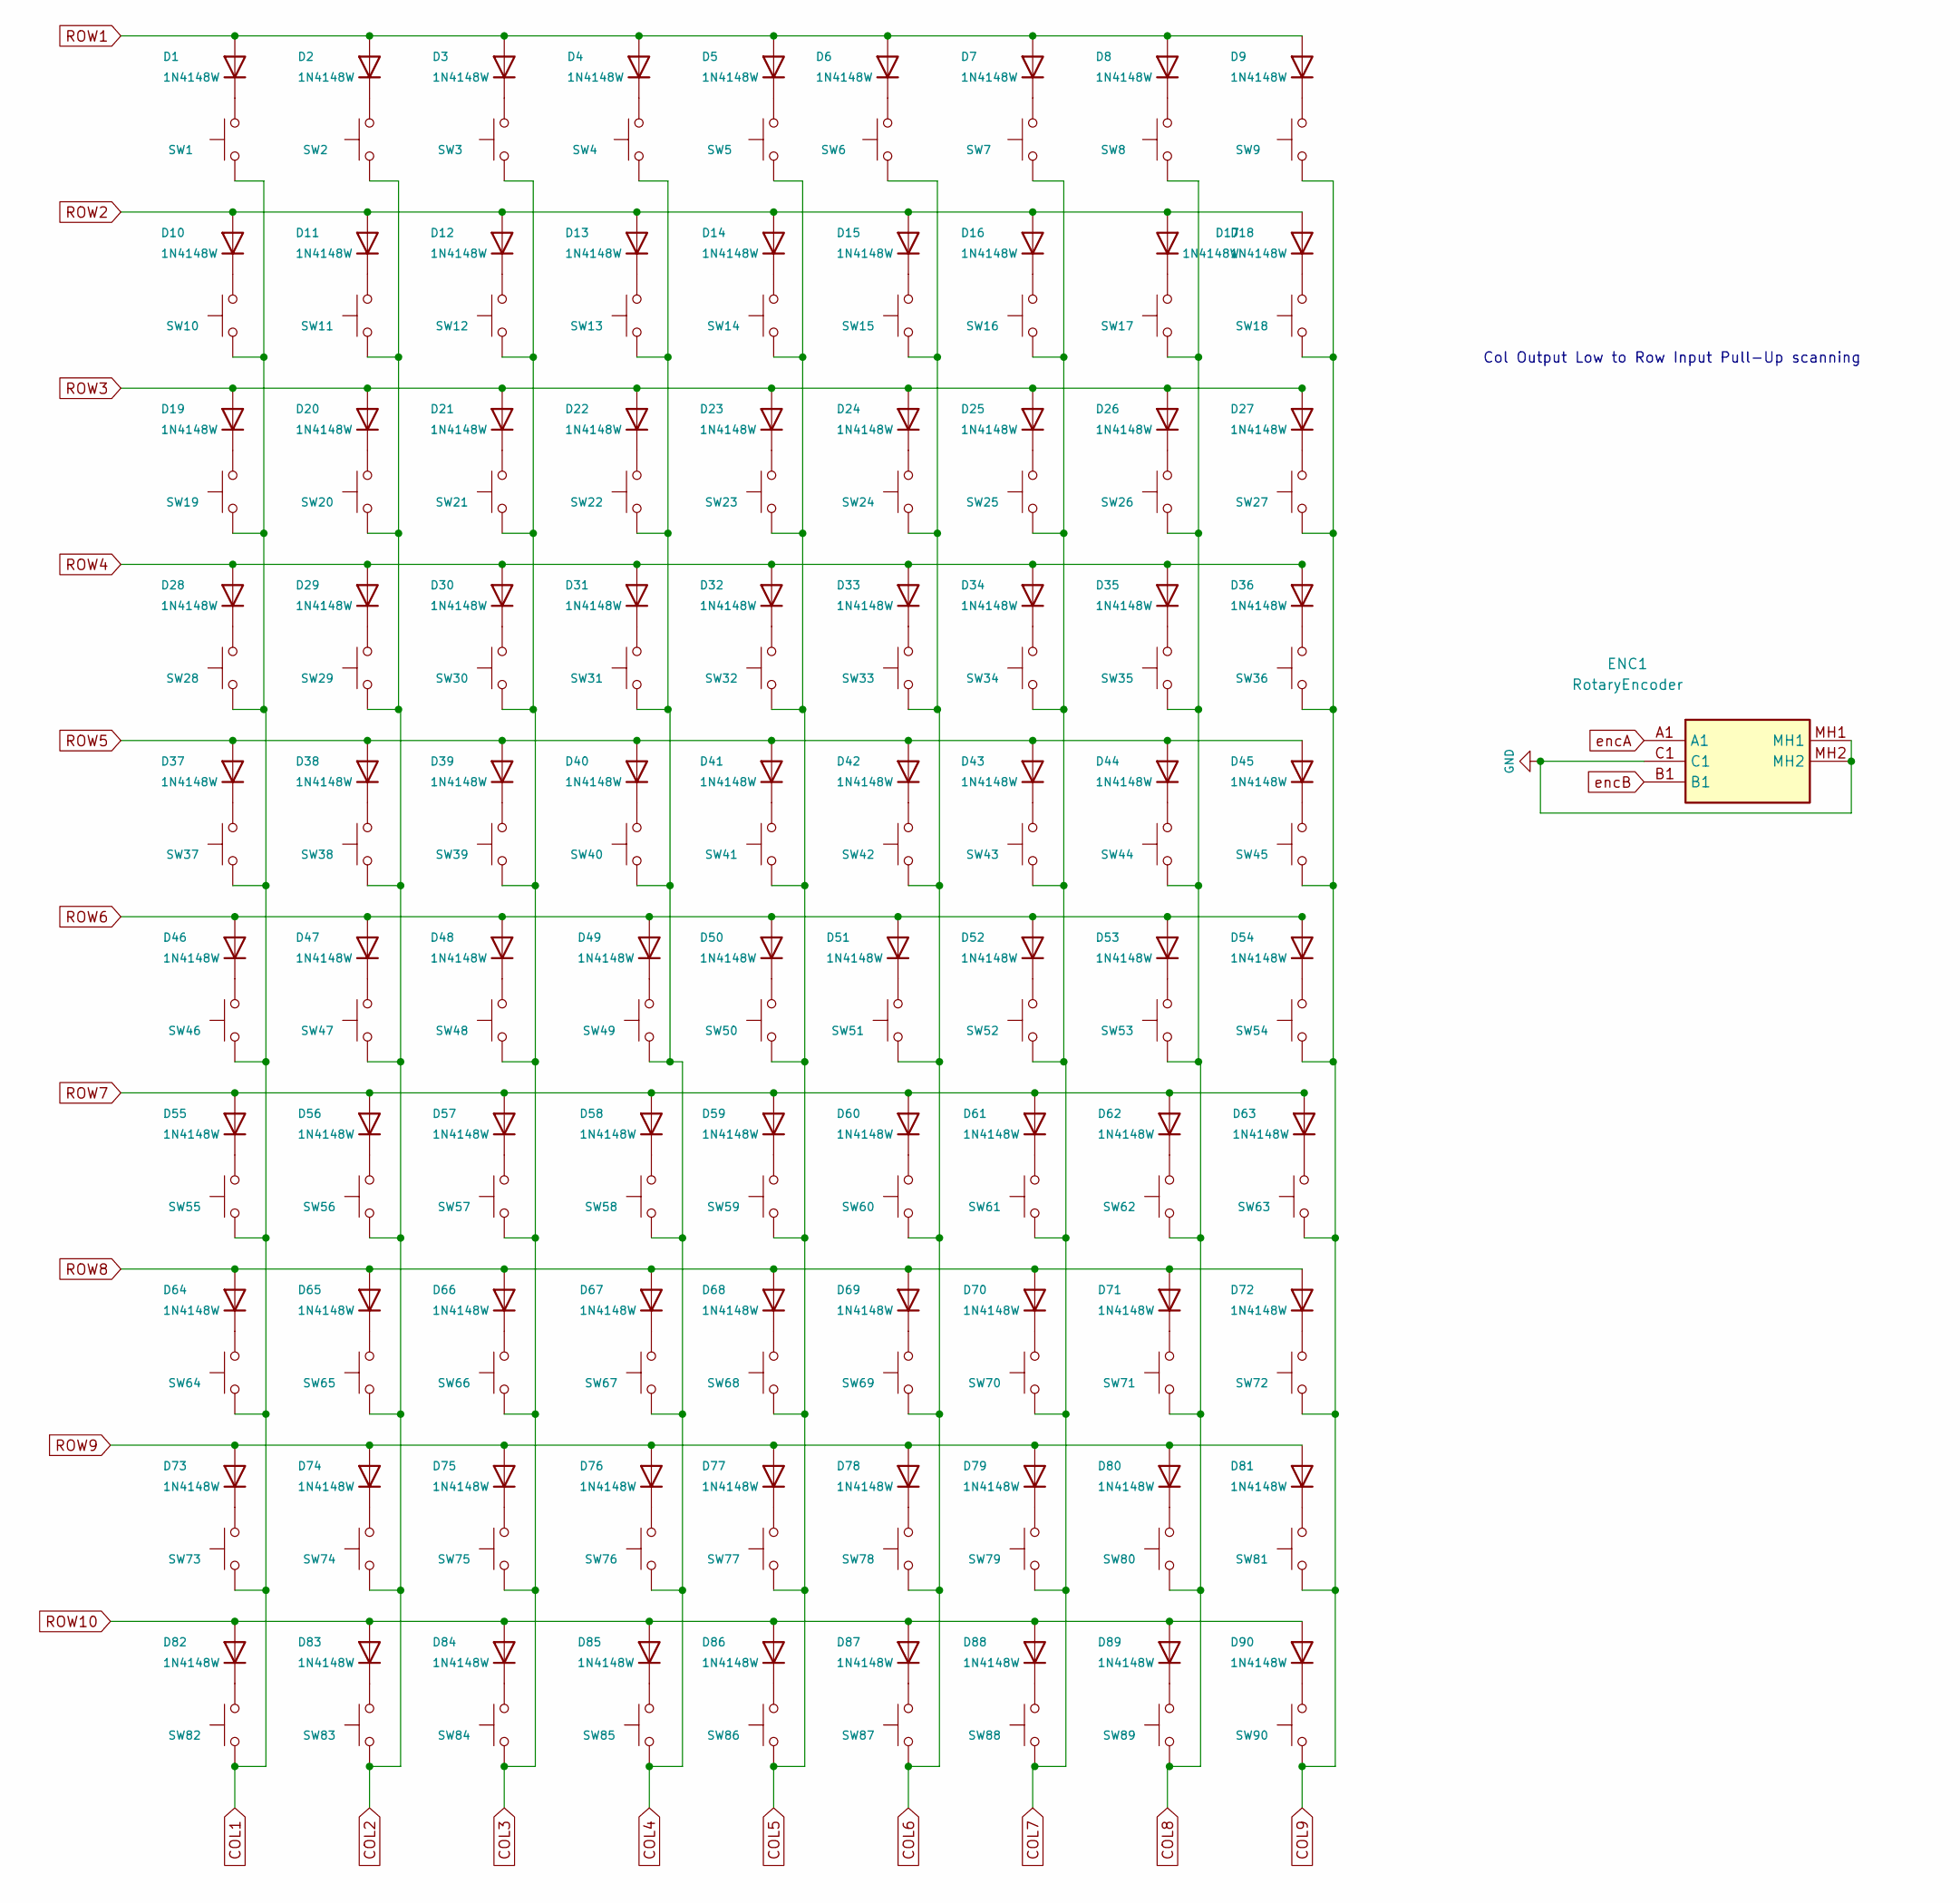
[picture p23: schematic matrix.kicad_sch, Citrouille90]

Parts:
D1, D2, D3, D4, D5, D6, D7, D8, D9, D10, D11, D12, D13, D14, D15, D16, D17, D18, D19, D20, D21, D22, D23, D24, D25, D26, D27, D28, D29, D30, D31, D32, D33, D34, D35, D36, D37, D38, D39, D40, D41, D42, D43, D44, D45, D46, D47, D48, D49, D50, D51, D52, D53, D54, D55, D56, D57, D58, D59, D60, D61, D62, D63, D64, D65, D66, D67, D68, D69, D70, D71, D72, D73, D74, D75, D76, D77, D78, D79, D80, D81, D82, D83, D84, D85, D86, D87, D88, D89, D90: 1N4148W; D_SOD-123; LCSC C81598
ENC1: RotaryEncoder; PES1240SN0024; Mouser Part Number 652-PES12-40S-N0024
SW1, SW2, SW3, SW4, SW5, SW6, SW7, SW8, SW9, SW10, SW11, SW12, SW13, SW14, SW15, SW16, SW17, SW18, SW19, SW20, SW21, SW22, SW23, SW24, SW25, SW26, SW27, SW28, SW29, SW30, SW31, SW32, SW33, SW34, SW35, SW36, SW37, SW38, SW39, SW40, SW41, SW42, SW43, SW44, SW45, SW46, SW47, SW48, SW49, SW50, SW51, SW52, SW53, SW54, SW55, SW56, SW57, SW58, SW59, SW60, SW61, SW62, SW63, SW64, SW65, SW66, SW67, SW68, SW69, SW70, SW71, SW72, SW73, SW74, SW75, SW76, SW77, SW78, SW79, SW80, SW81, SW82, SW83, SW84, SW85, SW86, SW87, SW88, SW89, SW90: SW_Kailh_Choc_V1_1.00u with LED indicator

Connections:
COL1: SW1.2, SW10.2, SW19.2, SW28.2, SW37.2, SW46.2, SW55.2, SW64.2, SW73.2, SW82.2; also elsewhere on the board
COL2: SW2.2, SW11.2, SW20.2, SW29.2, SW38.2, SW47.2, SW56.2, SW65.2, SW74.2, SW83.2; also elsewhere on the board
COL3: SW3.2, SW12.2, SW21.2, SW30.2, SW39.2, SW48.2, SW57.2, SW66.2, SW75.2, SW84.2; also elsewhere on the board
COL4: SW4.2, SW13.2, SW22.2, SW31.2, SW40.2, SW49.2, SW58.2, SW67.2, SW76.2, SW85.2; also elsewhere on the board
COL5: SW5.2, SW14.2, SW23.2, SW32.2, SW41.2, SW50.2, SW59.2, SW68.2, SW77.2, SW86.2; also elsewhere on the board
COL6: SW6.2, SW15.2, SW24.2, SW33.2, SW42.2, SW51.2, SW60.2, SW69.2, SW78.2, SW87.2; also elsewhere on the board
COL7: SW7.2, SW16.2, SW25.2, SW34.2, SW43.2, SW52.2, SW61.2, SW70.2, SW79.2, SW88.2; also elsewhere on the board
COL8: SW8.2, SW17.2, SW26.2, SW35.2, SW44.2, SW53.2, SW62.2, SW71.2, SW80.2, SW89.2; also elsewhere on the board
COL9: SW9.2, SW18.2, SW27.2, SW36.2, SW45.2, SW54.2, SW63.2, SW72.2, SW81.2, SW90.2; also elsewhere on the board
unnamed: D1.1 (K), SW1.1
unnamed: D2.1 (K), SW2.1
unnamed: D3.1 (K), SW3.1
unnamed: D4.1 (K), SW4.1
unnamed: D5.1 (K), SW5.1
unnamed: D6.1 (K), SW6.1
unnamed: D7.1 (K), SW7.1
unnamed: D8.1 (K), SW8.1
unnamed: D9.1 (K), SW9.1
unnamed: D10.1 (K), SW10.1
unnamed: D11.1 (K), SW11.1
unnamed: D12.1 (K), SW12.1
unnamed: D13.1 (K), SW13.1
unnamed: D14.1 (K), SW14.1
unnamed: D15.1 (K), SW15.1
unnamed: D16.1 (K), SW16.1
unnamed: D17.1 (K), SW17.1
unnamed: D18.1 (K), SW18.1
unnamed: D19.1 (K), SW19.1
unnamed: D20.1 (K), SW20.1
unnamed: D21.1 (K), SW21.1
unnamed: D22.1 (K), SW22.1
unnamed: D23.1 (K), SW23.1
unnamed: D24.1 (K), SW24.1
unnamed: D25.1 (K), SW25.1
unnamed: D26.1 (K), SW26.1
unnamed: D27.1 (K), SW27.1
unnamed: D28.1 (K), SW28.1
unnamed: D29.1 (K), SW29.1
unnamed: D30.1 (K), SW30.1
unnamed: D31.1 (K), SW31.1
unnamed: D32.1 (K), SW32.1
unnamed: D33.1 (K), SW33.1
unnamed: D34.1 (K), SW34.1
unnamed: D35.1 (K), SW35.1
unnamed: D36.1 (K), SW36.1
unnamed: D37.1 (K), SW37.1
unnamed: D38.1 (K), SW38.1
unnamed: D39.1 (K), SW39.1
unnamed: D40.1 (K), SW40.1
unnamed: D41.1 (K), SW41.1
unnamed: D42.1 (K), SW42.1
unnamed: D43.1 (K), SW43.1
unnamed: D44.1 (K), SW44.1
unnamed: D45.1 (K), SW45.1
unnamed: D46.1 (K), SW46.1
unnamed: D47.1 (K), SW47.1
unnamed: D48.1 (K), SW48.1
unnamed: D49.1 (K), SW49.1
unnamed: D50.1 (K), SW50.1
unnamed: D51.1 (K), SW51.1
unnamed: D52.1 (K), SW52.1
unnamed: D53.1 (K), SW53.1
unnamed: D54.1 (K), SW54.1
unnamed: D55.1 (K), SW55.1
unnamed: D56.1 (K), SW56.1
unnamed: D57.1 (K), SW57.1
unnamed: D58.1 (K), SW58.1
unnamed: D59.1 (K), SW59.1
unnamed: D60.1 (K), SW60.1
unnamed: D61.1 (K), SW61.1
unnamed: D62.1 (K), SW62.1
unnamed: D63.1 (K), SW63.1
unnamed: D64.1 (K), SW64.1
unnamed: D65.1 (K), SW65.1
unnamed: D66.1 (K), SW66.1
unnamed: D67.1 (K), SW67.1
unnamed: D68.1 (K), SW68.1
unnamed: D69.1 (K), SW69.1
unnamed: D70.1 (K), SW70.1
unnamed: D71.1 (K), SW71.1
unnamed: D72.1 (K), SW72.1
unnamed: D73.1 (K), SW73.1
unnamed: D74.1 (K), SW74.1
unnamed: D75.1 (K), SW75.1
unnamed: D76.1 (K), SW76.1
unnamed: D77.1 (K), SW77.1
unnamed: D78.1 (K), SW78.1
unnamed: D79.1 (K), SW79.1
unnamed: D80.1 (K), SW80.1
unnamed: D81.1 (K), SW81.1
unnamed: D82.1 (K), SW82.1
unnamed: D83.1 (K), SW83.1
unnamed: D84.1 (K), SW84.1
unnamed: D85.1 (K), SW85.1
unnamed: D86.1 (K), SW86.1
unnamed: D87.1 (K), SW87.1
unnamed: D88.1 (K), SW88.1
unnamed: D89.1 (K), SW89.1
unnamed: D90.1 (K), SW90.1
unnamed: ENC1.C1, ENC1.MH1, ENC1.MH2
ROW1: D1.2 (A), D2.2 (A), D3.2 (A), D4.2 (A), D5.2 (A), D6.2 (A), D7.2 (A), D8.2 (A), D9.2 (A); also elsewhere on the board
ROW2: D10.2 (A), D11.2 (A), D12.2 (A), D13.2 (A), D14.2 (A), D15.2 (A), D16.2 (A), D17.2 (A), D18.2 (A); also elsewhere on the board
ROW3: D19.2 (A), D20.2 (A), D21.2 (A), D22.2 (A), D23.2 (A), D24.2 (A), D25.2 (A), D26.2 (A), D27.2 (A); also elsewhere on the board
ROW4: D28.2 (A), D29.2 (A), D30.2 (A), D31.2 (A), D32.2 (A), D33.2 (A), D34.2 (A), D35.2 (A), D36.2 (A); also elsewhere on the board
ROW5: D37.2 (A), D38.2 (A), D39.2 (A), D40.2 (A), D41.2 (A), D42.2 (A), D43.2 (A), D44.2 (A), D45.2 (A); also elsewhere on the board
ROW6: D46.2 (A), D47.2 (A), D48.2 (A), D49.2 (A), D50.2 (A), D51.2 (A), D52.2 (A), D53.2 (A), D54.2 (A); also elsewhere on the board
ROW7: D55.2 (A), D56.2 (A), D57.2 (A), D58.2 (A), D59.2 (A), D60.2 (A), D61.2 (A), D62.2 (A), D63.2 (A); also elsewhere on the board
ROW8: D64.2 (A), D65.2 (A), D66.2 (A), D67.2 (A), D68.2 (A), D69.2 (A), D70.2 (A), D71.2 (A), D72.2 (A); also elsewhere on the board
ROW9: D73.2 (A), D74.2 (A), D75.2 (A), D76.2 (A), D77.2 (A), D78.2 (A), D79.2 (A), D80.2 (A), D81.2 (A); also elsewhere on the board
ROW10: D82.2 (A), D83.2 (A), D84.2 (A), D85.2 (A), D86.2 (A), D87.2 (A), D88.2 (A), D89.2 (A), D90.2 (A); also elsewhere on the board

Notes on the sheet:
Col Output Low to Row Input Pull-Up scanning

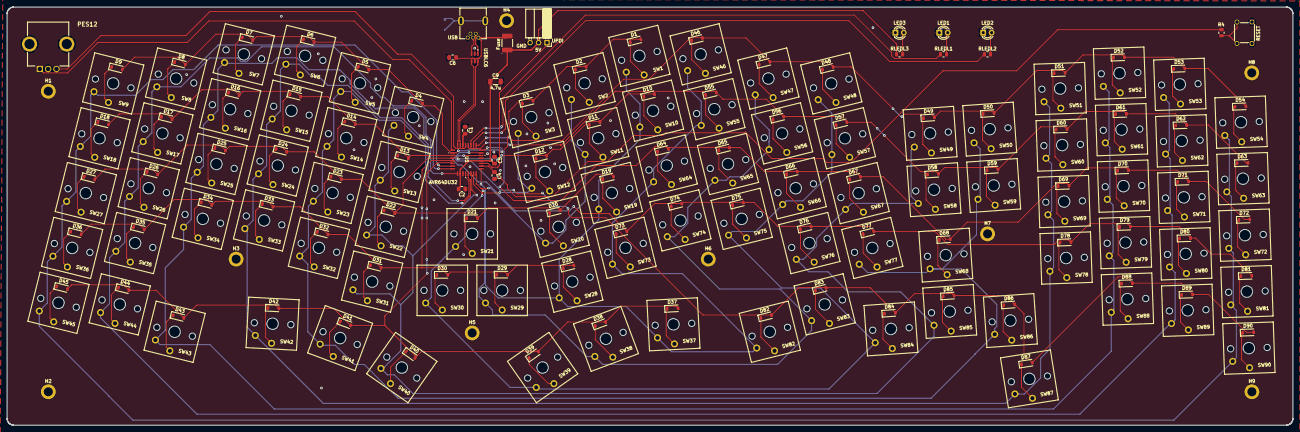
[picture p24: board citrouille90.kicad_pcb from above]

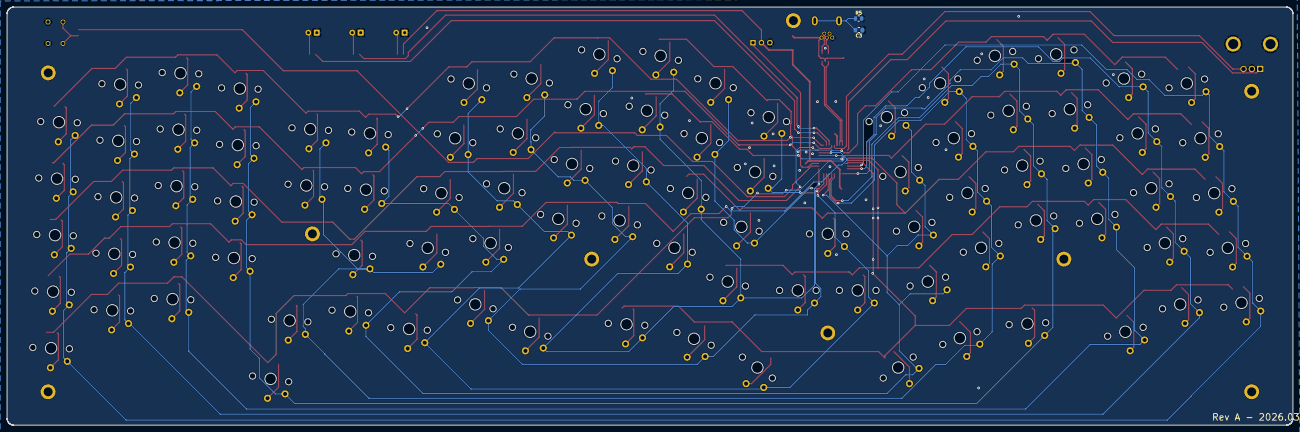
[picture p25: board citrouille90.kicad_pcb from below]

Board: 2 copper layers, 386.7 x 125.7 mm, 211 parts (2 on the bottom side), 128 nets.

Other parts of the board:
Fuse: 500mA PTC 1812; FUSM4632X85
PES12: RotaryEncoder; PES1240SN0024
RESET: MJTP1230; SW_MJTP1230
USB: USB mini b connector; usb mini connector
USBLC6: USBLC6-2SC6; SOT-23-6

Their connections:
+5V: Fuse.1; also elsewhere on the board
/D in+: USB.3 (D+), USBLC6.3
/D in-: USB.2 (D-), USBLC6.1
/D out+: USBLC6.4; also elsewhere on the board
/D out-: USBLC6.6; also elsewhere on the board
/VBUS: Fuse.2, USB.1 (VBUS), USBLC6.5; also elsewhere on the board
GND: PES12.C1, PES12.MH1, PES12.MH2, RESET.1_1, RESET.1_2, USB.5 (GND), USBLC6.2; also elsewhere on the board
unnamed 112: USB.6; also elsewhere on the board
unnamed 116: RESET.2_1, RESET.2_2; also elsewhere on the board
encA: PES12.A1; also elsewhere on the board
encB: PES12.B1; also elsewhere on the board

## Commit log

2026-03-11 Majority of PCB design
    [HRO-U-M-M5DD-W-1.step, Kailh_PG151101S11.step, MF-MSMF050-2.STEP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]
2026-03-19 PCB work
    [citrouille90.kicad_pcb, citrouille90.kicad_sch]
2026-03-19 Fine tune PCB
    [citrouille90.kicad_pcb, citrouille90.kicad_sch]
2026-03-25 Fine tune silkscreen graphics
2026-03-31 Add RC filter to encoder
    [citrouille90.kicad_sch, matrix.kicad_sch]
2026-05-01 Clean split of HW and FW in two separate repos
    [position clefs clavier.xlsx]
2026-05-16 Final update to PCB prior to generation of gerber and drill files
2026-05-17 Update documentation, generate gerbers
    [citrouille90-B_Cu.gbl, citrouille90-B_Mask.gbs, citrouille90-B_Paste.gbp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]
